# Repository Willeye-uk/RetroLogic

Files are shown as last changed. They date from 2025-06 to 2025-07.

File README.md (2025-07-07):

# **The RetroLogic 6502 SBC - KiCad 9 Files ([Ben Eater](https://eater.net/6502) Inspired)**

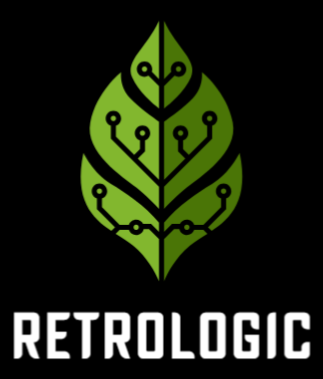
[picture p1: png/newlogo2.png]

---

Welcome to the repository for the **KiCad 9 design files** of a single board computer (SBC) based on the classic **W65C02S microprocessor**. This project draws heavy inspiration from [Ben Eater's excellent 6502 computer series](https://eater.net/6502), expanding upon it with a range of features for greater versatility and modern connectivity.

## **Features**

This SBC design aims to provide a robust platform for learning and experimenting with the 6502. Key features include:

* **W65C02S Processor:** Capable of running up to **14 MHz**.
* **Memory:**
    * **62256 SRAM:** For fast read/write memory operations.
    * **28C256 EEPROM:** For storing your programs and firmware.
* **Input/Output:**
    * **65C22 Versatile Interface Adapter (VIA):** Provides programmable parallel I/O, timers, and shift registers.
    * **65C51 Asynchronous Communications Interface Adapter (ACIA):** For serial communication capabilities.
* **Connectivity:**
    * **DB9 Serial Port:** Standard serial connector for PC communication (via MAX232 level shifter).
    * **FTDI Breakout Serial Socket:** Convenient header for connecting an FTDI serial-to-USB adapter.
    * **SD Card Socket:** For mass storage, enabling easier program loading and data logging.
    * **LCD Screen Connector:** Directly interface with character LCDs.
* **Power & Expansion:**
    * **USB-B Power Socket:** Modern and widely available power input.
    * **Power Switch:** For easy power control.
    * **Crystal Socket:** Flexible clocking options, allowing for different crystal frequencies.
    * **Switchable Voltage for Add-ons:** Provides configurable power for external modules and expansion boards.
    * **Expansion Port:** Example diagnostic board included.
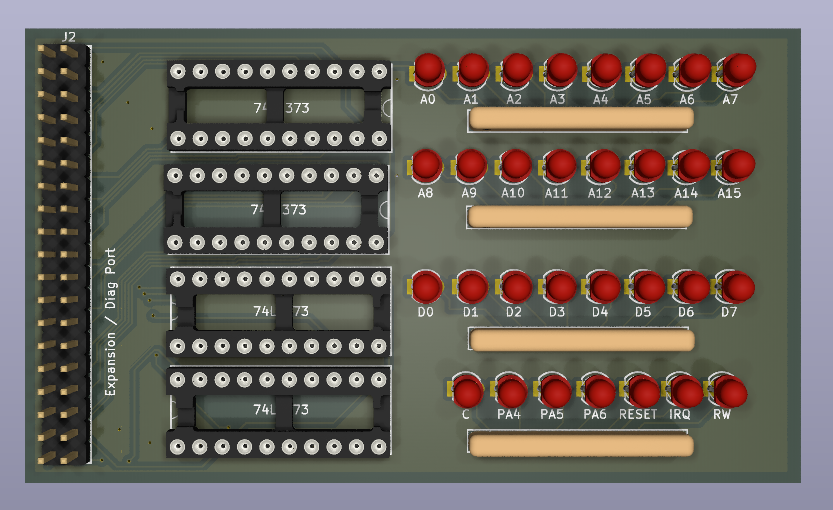
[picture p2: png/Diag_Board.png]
    
    * **Sound Card:** Expansion sound card and demo program.
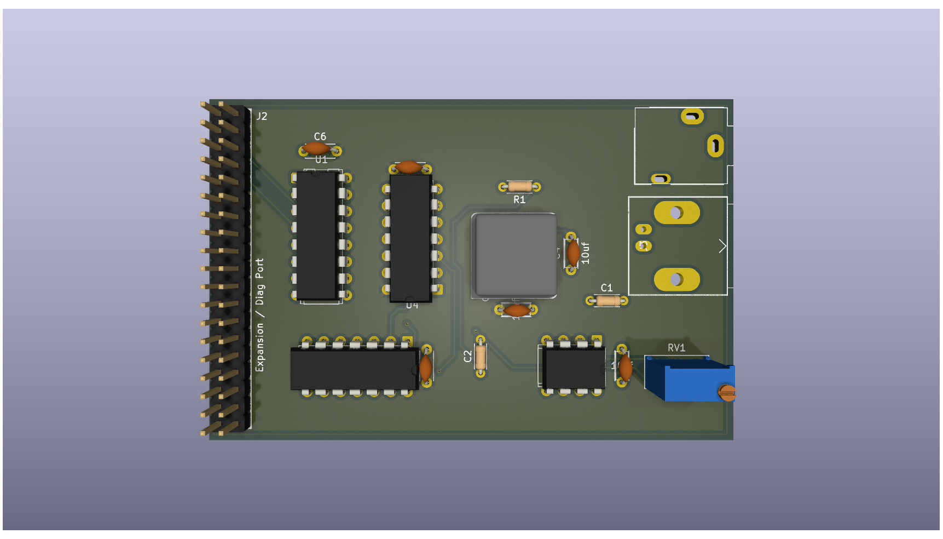
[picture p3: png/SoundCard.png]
    
    * **Terminal Card:** Expansion VGA terminal based on https://geoffg.net/terminal.html

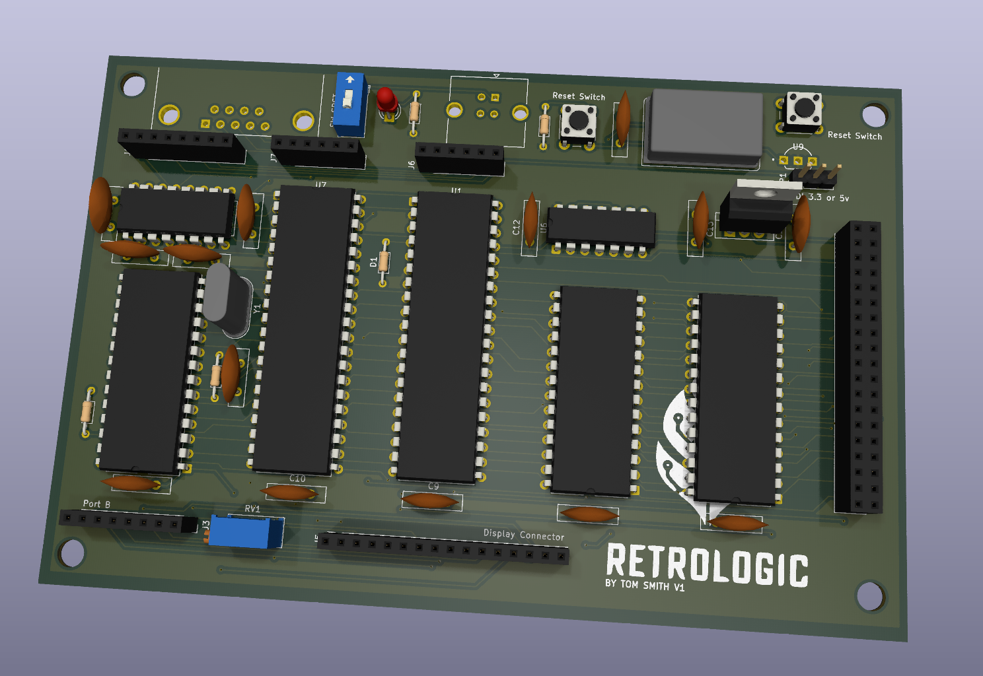
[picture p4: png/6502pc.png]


## **Getting Started**

To explore or modify this design, you'll need **KiCad 9**.

**Clone this repository: \
** Bash \
git clone https://github.com/Willeye-uk/RetroLogic.git

1. 
2. **Open the project in KiCad 9:** Navigate to the cloned directory and open the `.kicad_pro` file.

From there, you can view the schematics, examine the PCB layout, and generate manufacturing files if you wish to build your own board. Or use the ones provided in Gerber Files dir.

## **Contributing**

Contributions are welcome! If you find issues, have suggestions for improvements, or want to add features, feel free to open an issue or submit a pull request.

## **License**

This project is open-source. Please refer to the `LICENSE` file (if present) for details.

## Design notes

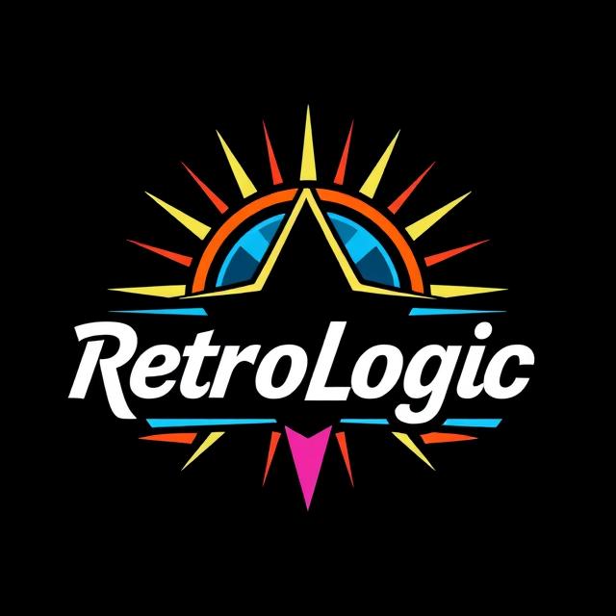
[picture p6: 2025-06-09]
png/output.jpg

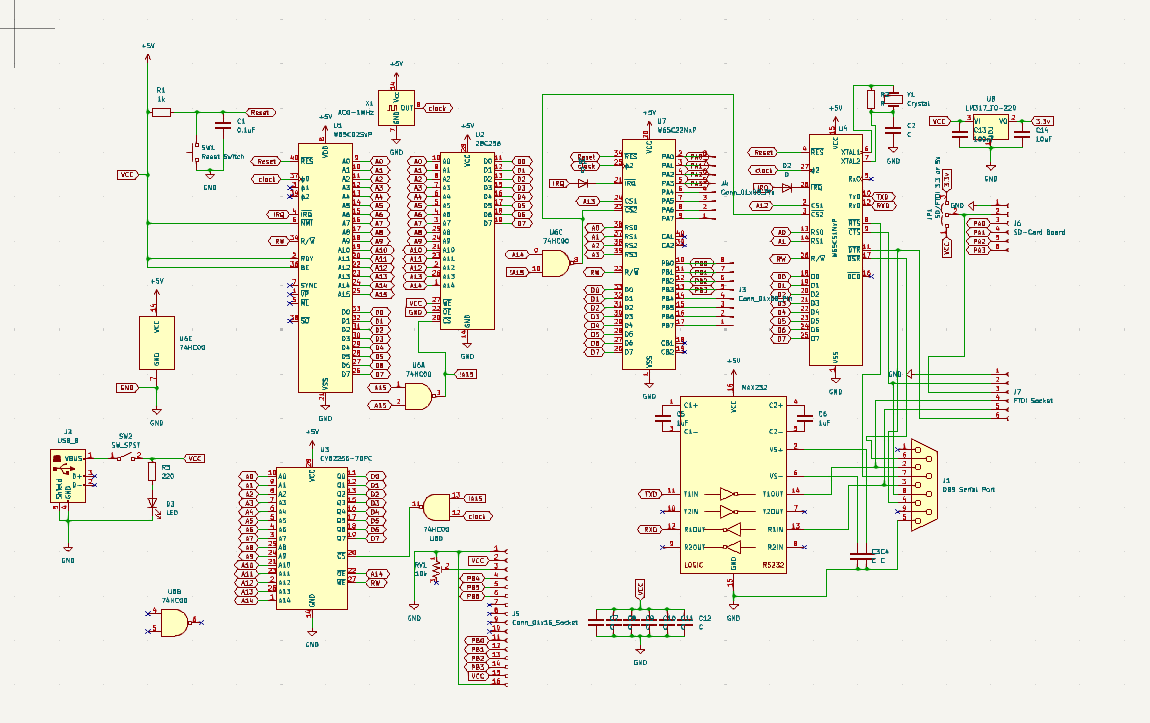
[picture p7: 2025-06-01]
png/layout1.png

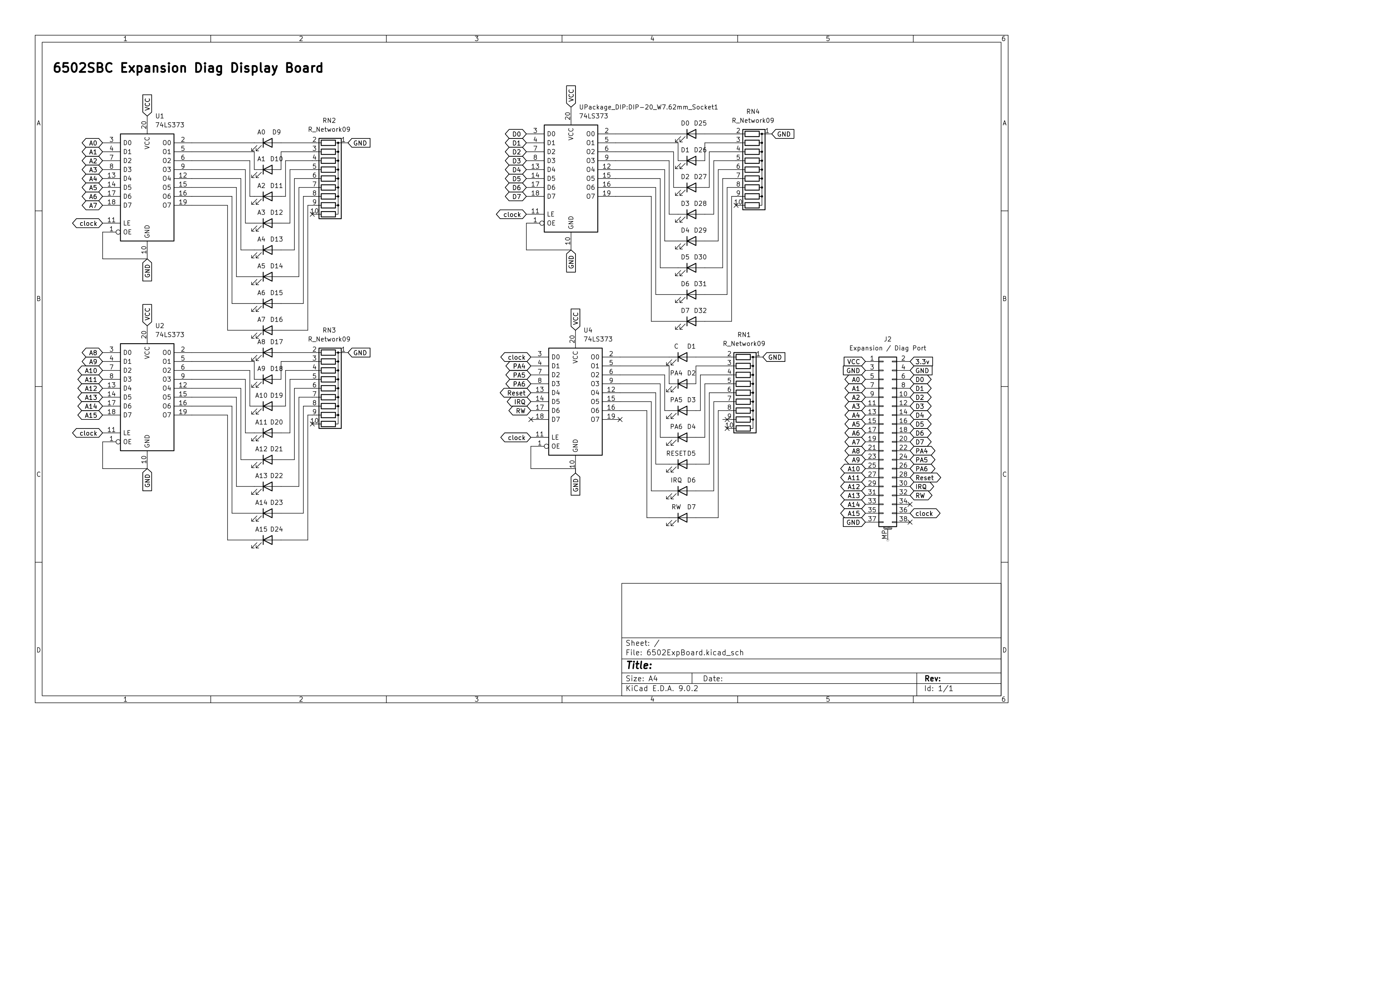
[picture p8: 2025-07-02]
png/Diag.png

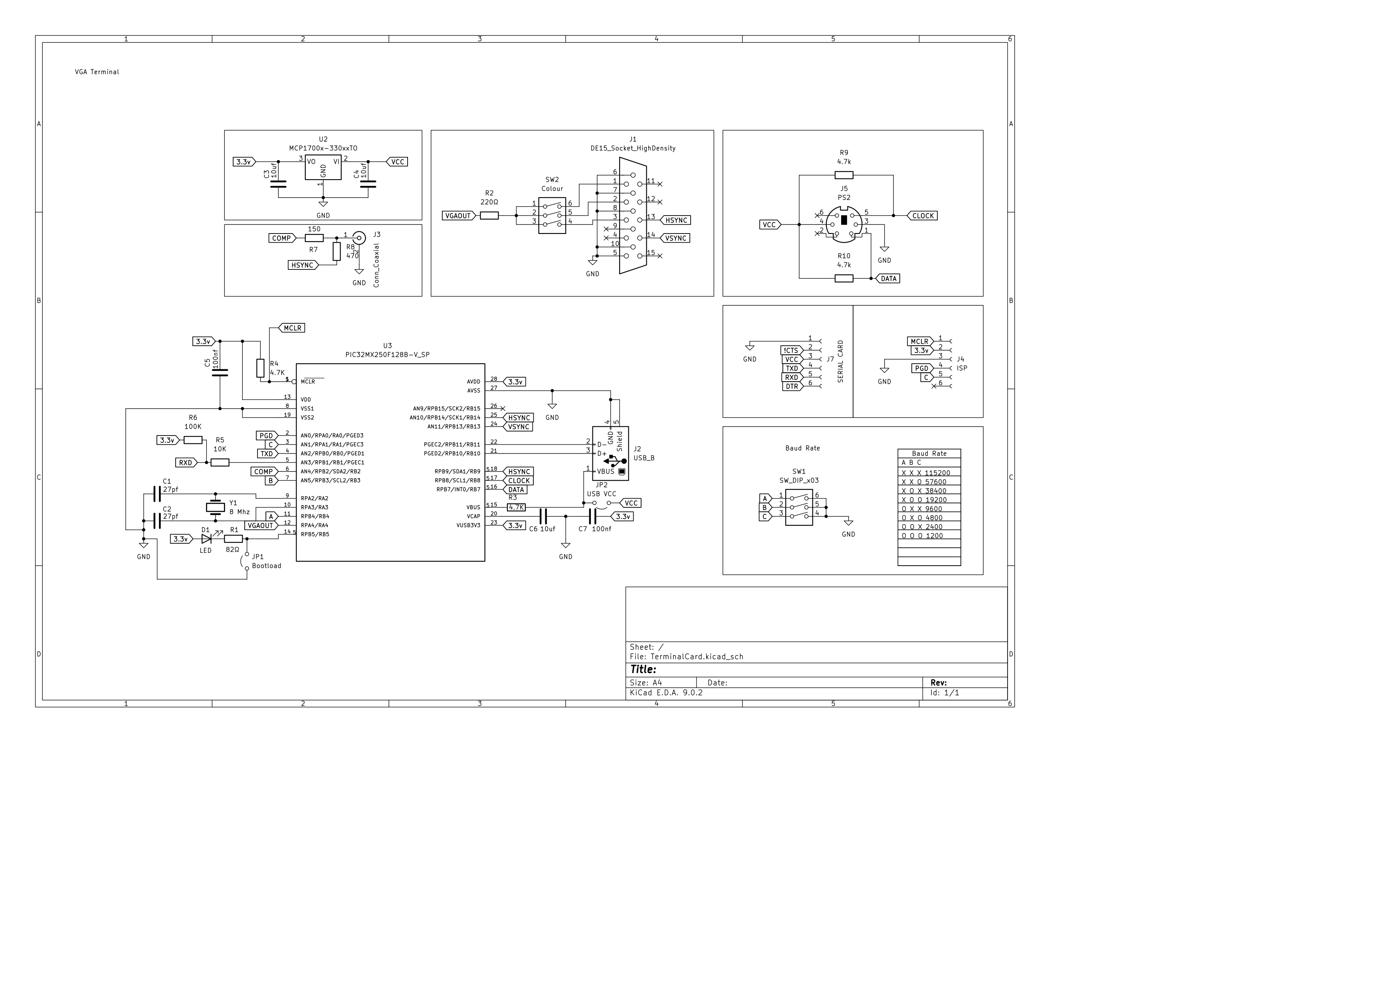
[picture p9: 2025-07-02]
png/terminal.png

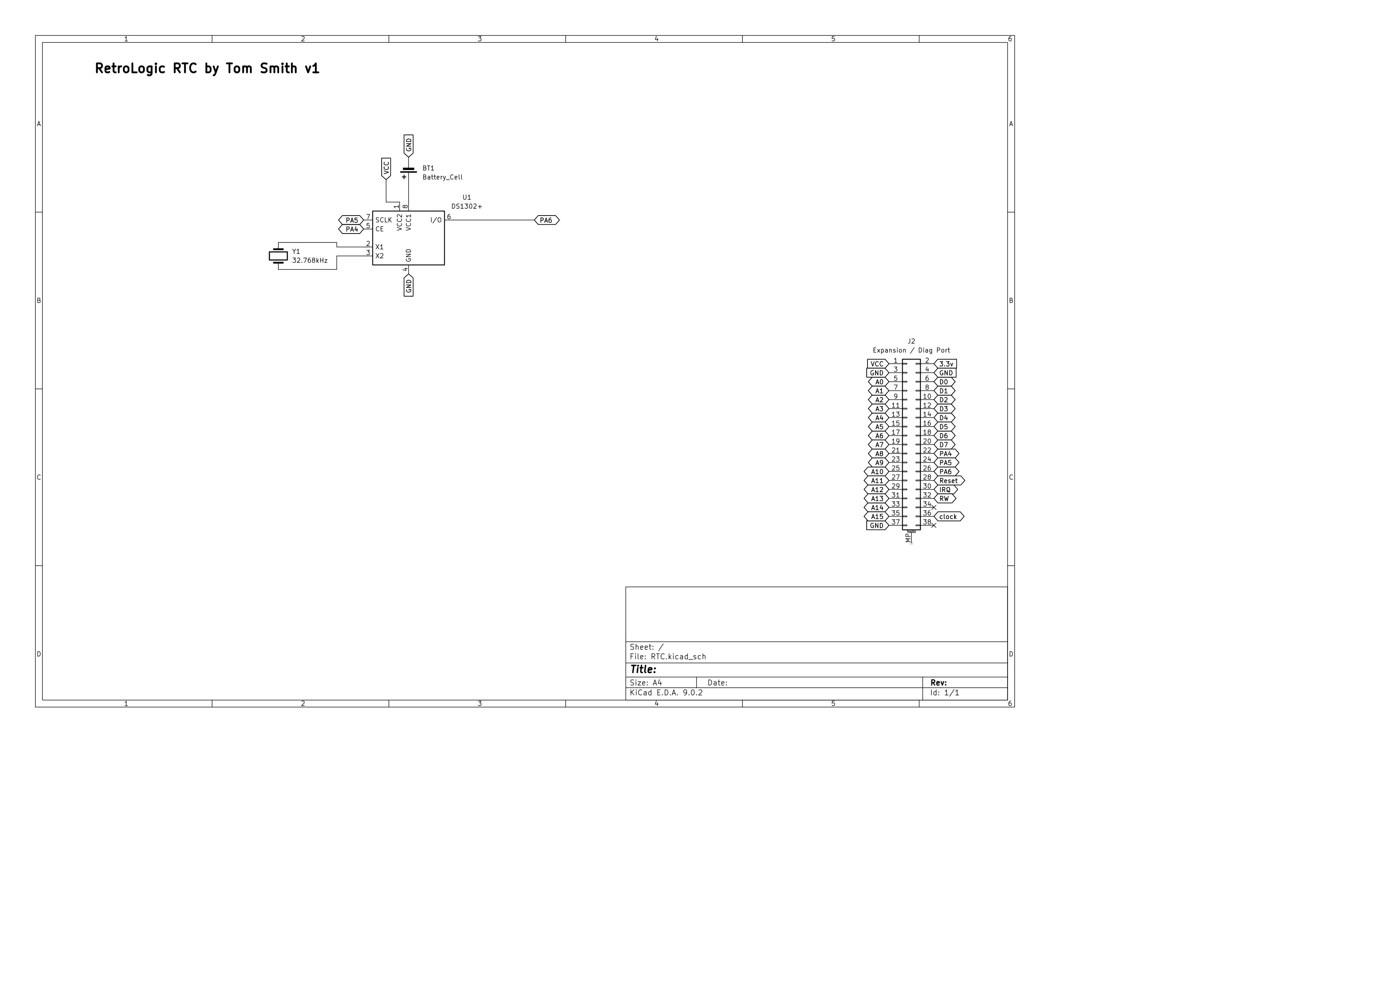
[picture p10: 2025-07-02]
png/rtc.png

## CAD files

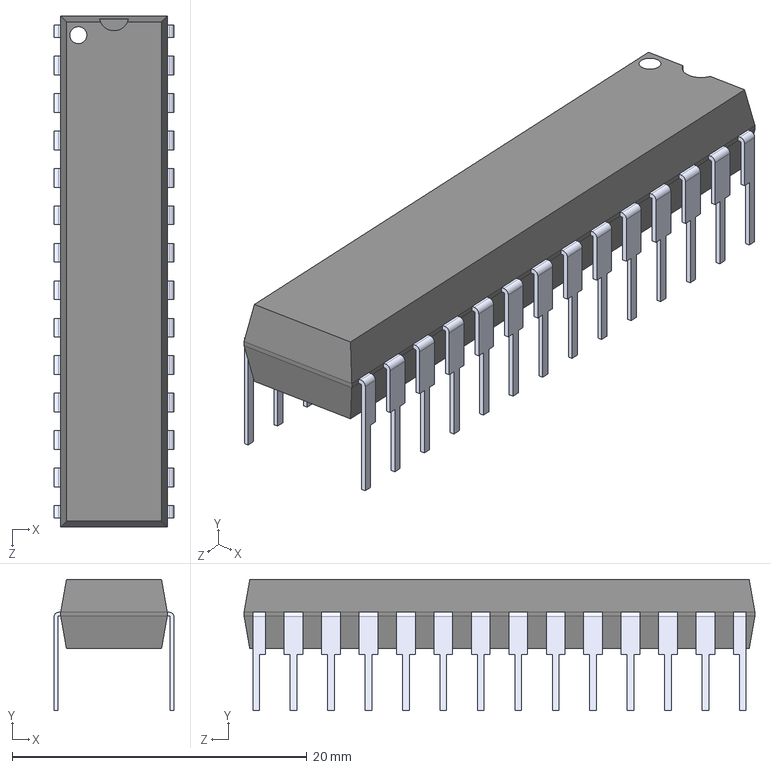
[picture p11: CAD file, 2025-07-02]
PIC32MX250F128B-V_SP/PIC32MX250F128B-V_SP.step
8.13 x 8.89 x 34.7 mm

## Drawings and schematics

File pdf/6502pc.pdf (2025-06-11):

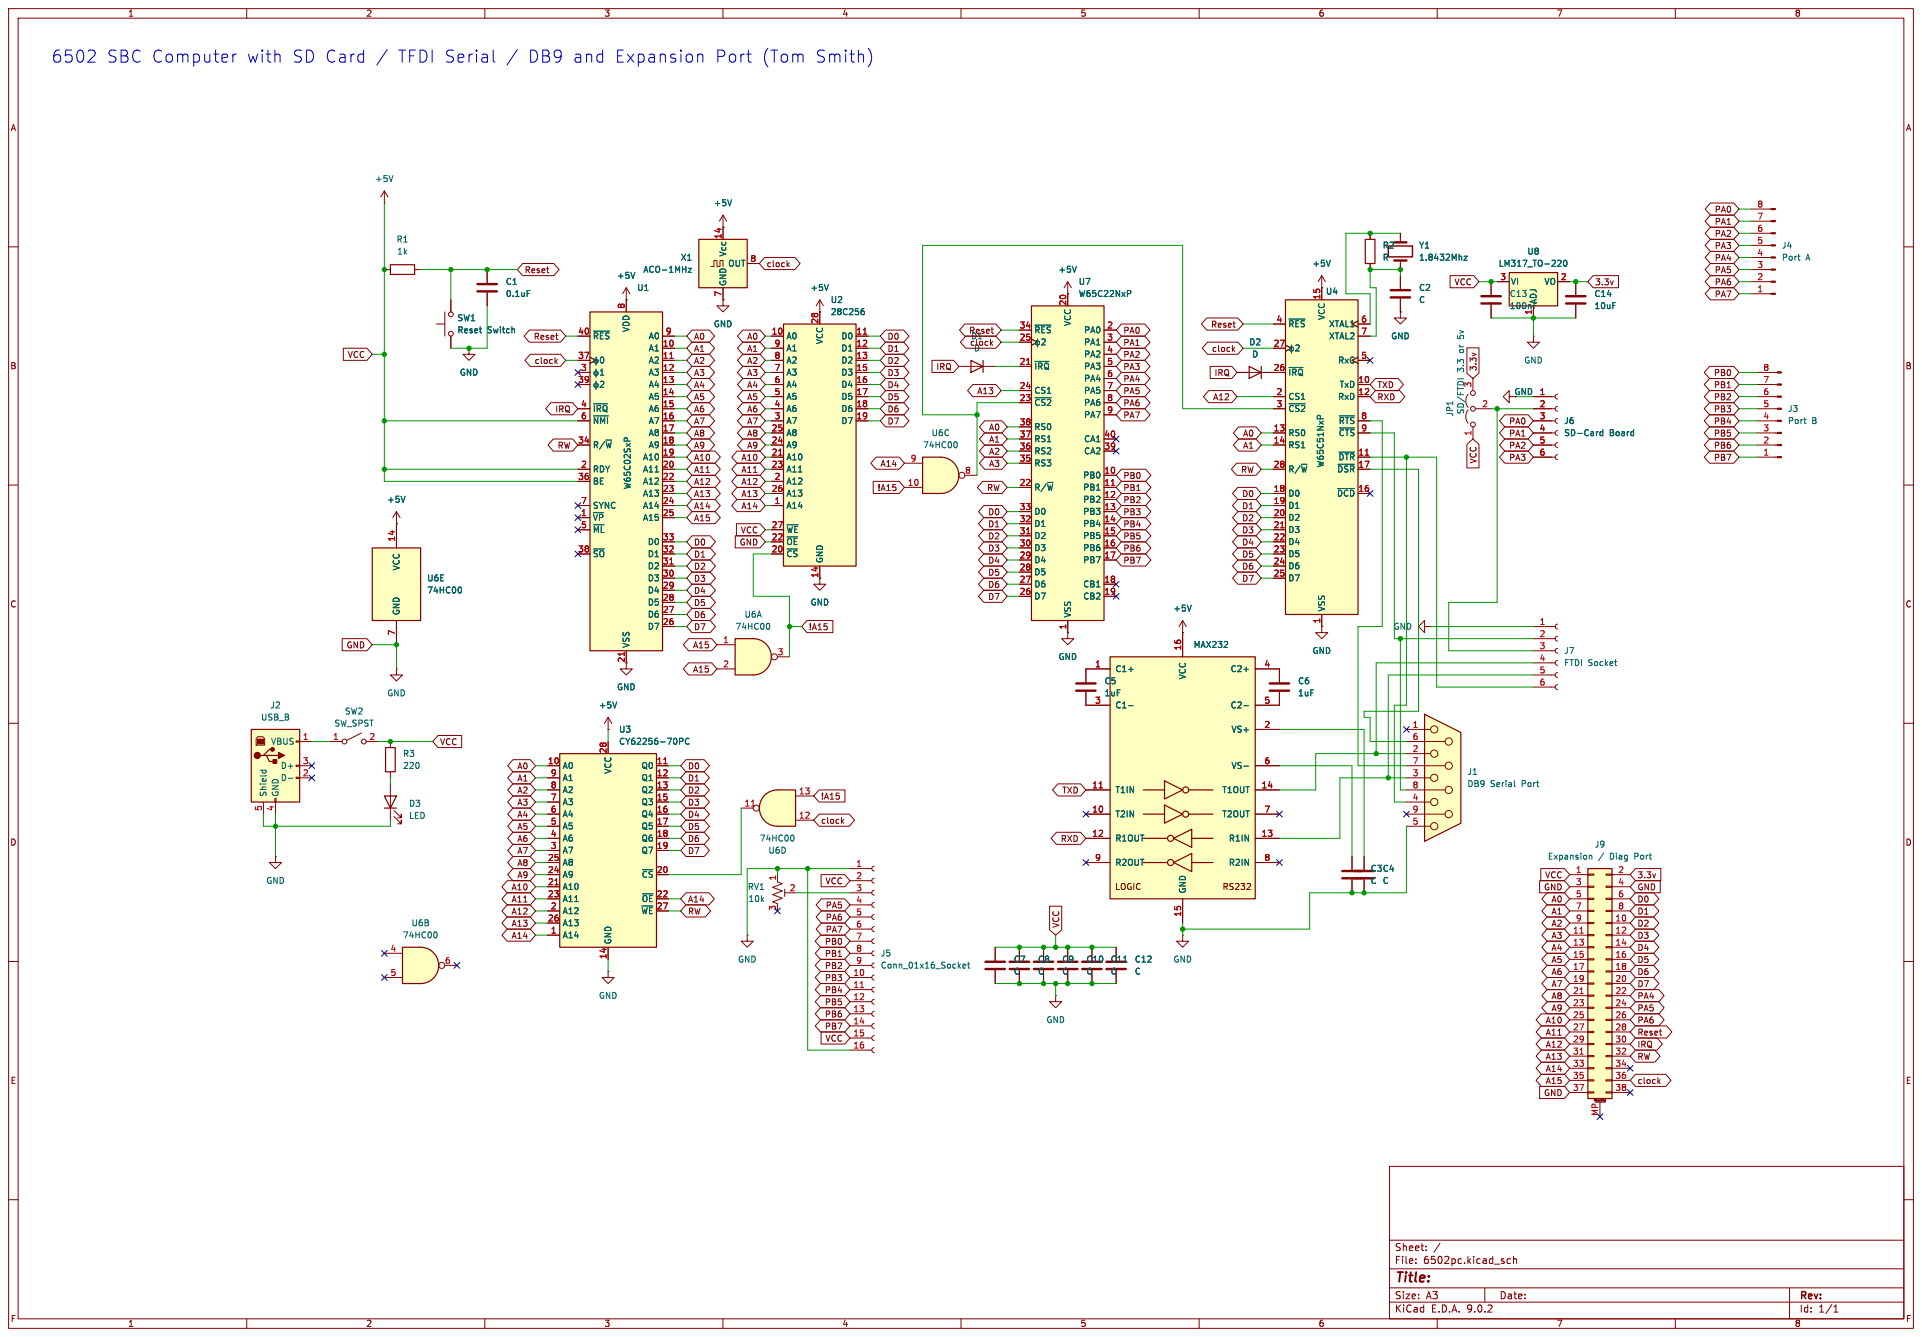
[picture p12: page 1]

6502 SBC Computer with SD Card / TFDI Serial / DB9 and Expansion Port (Tom Smith) C1

SW1 Reset Switch VCC 14 GND

1 XTAL1 6 XTAL2 7 RxC 5 TxD 10 RxD 12 ~{RTS}8 ~{CTS}9 ~{DTR} 11 ~{DSR} 17 ~{DCD} 16 R2 R
U4 W65C51NxP

1 XTAL1 6 XTAL2 7 RxC 5 TxD 10 RxD 12 ~{RTS}8 ~{CTS}9 ~{DTR} 11 ~{DSR} 17 ~{DCD} 16 U4 W65C51NxP

3 JP1 SD/FTDI 3.3 or 5v C10 C GND

Id: 1/1 Title: File: 6502pc.kicad_sch Sheet: /

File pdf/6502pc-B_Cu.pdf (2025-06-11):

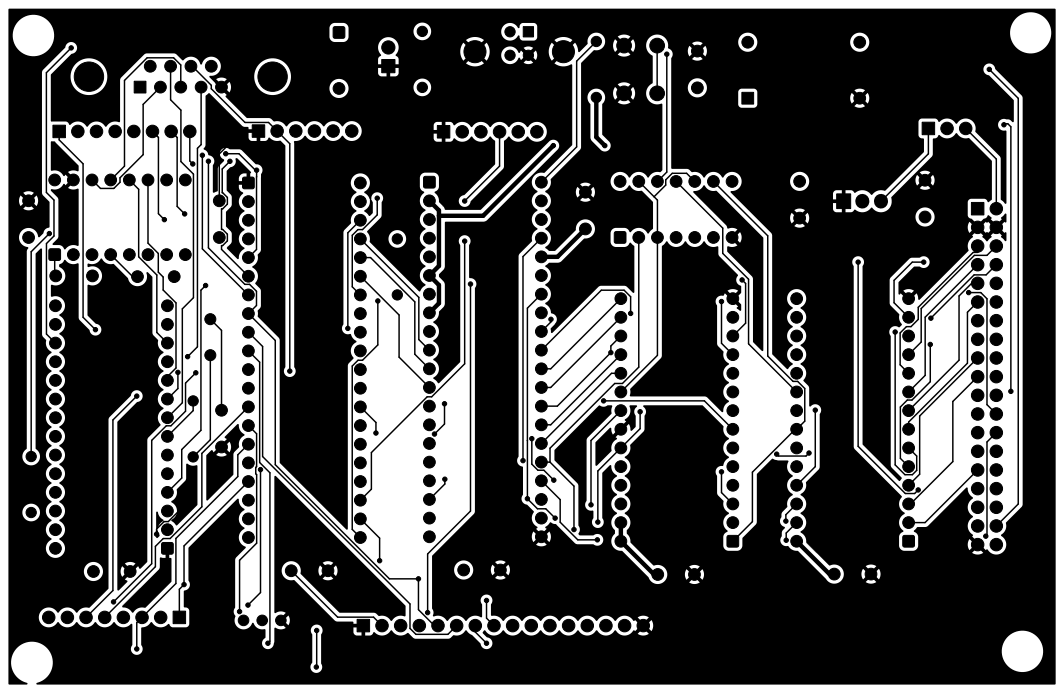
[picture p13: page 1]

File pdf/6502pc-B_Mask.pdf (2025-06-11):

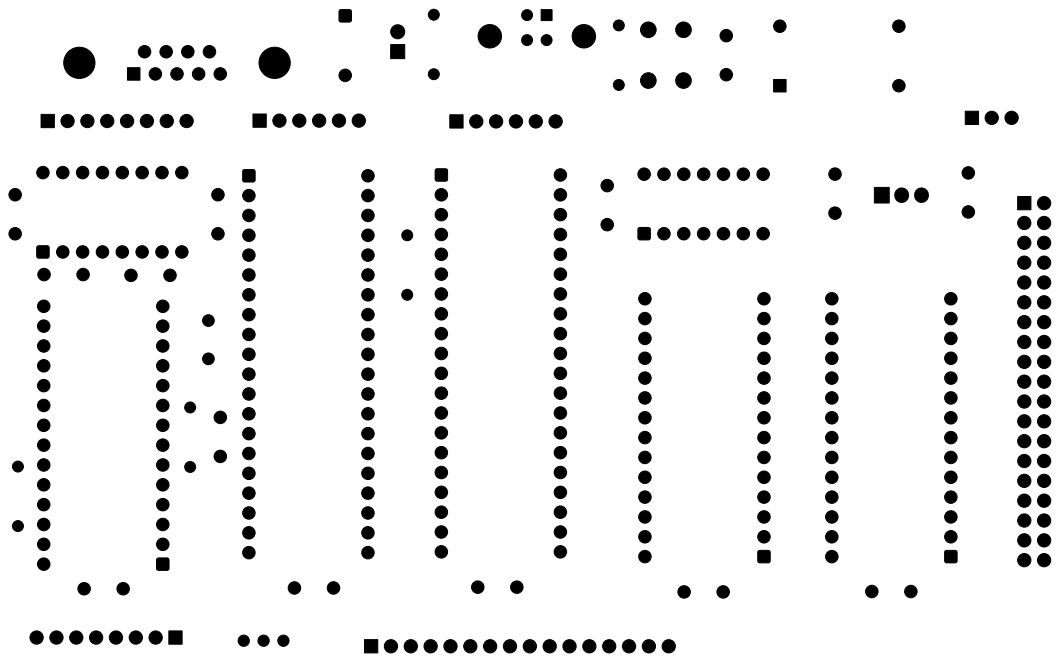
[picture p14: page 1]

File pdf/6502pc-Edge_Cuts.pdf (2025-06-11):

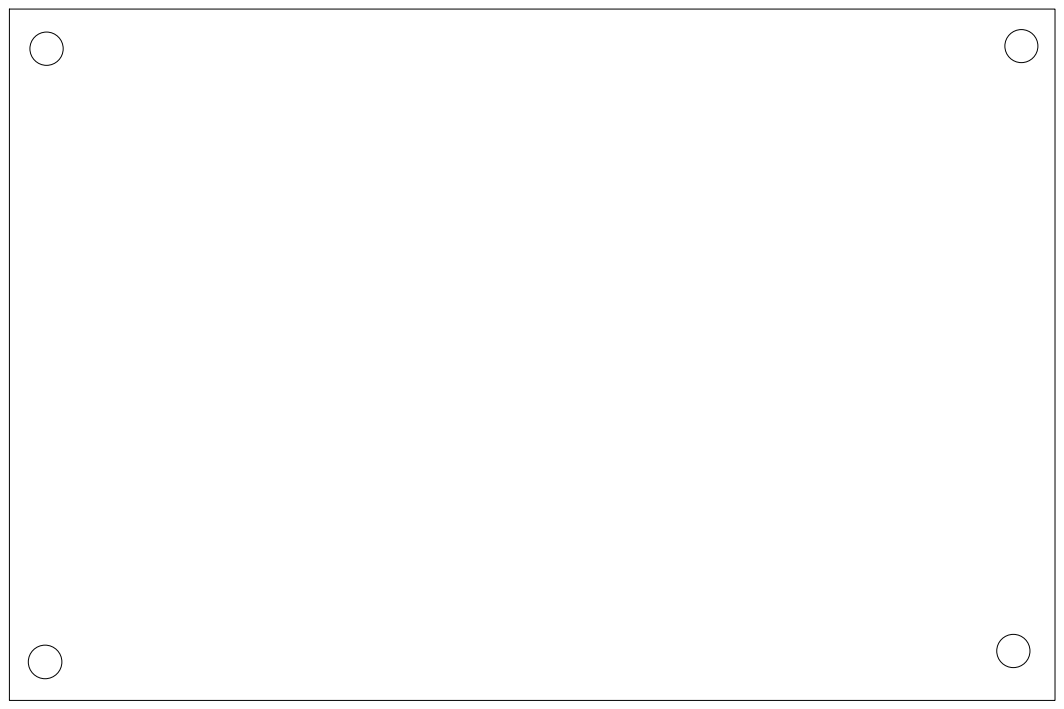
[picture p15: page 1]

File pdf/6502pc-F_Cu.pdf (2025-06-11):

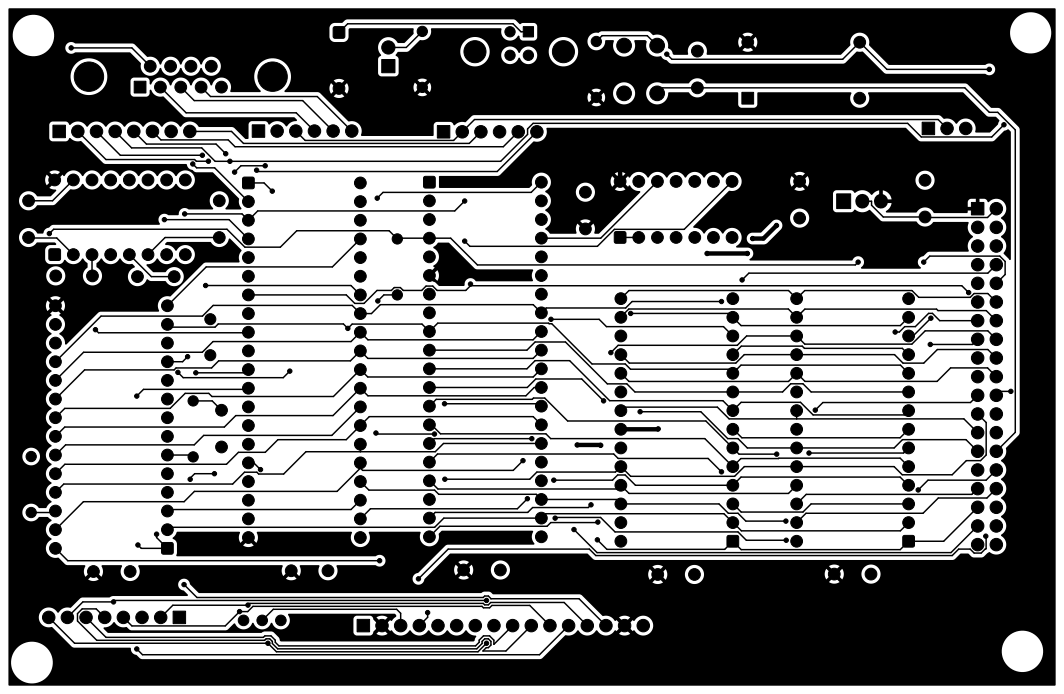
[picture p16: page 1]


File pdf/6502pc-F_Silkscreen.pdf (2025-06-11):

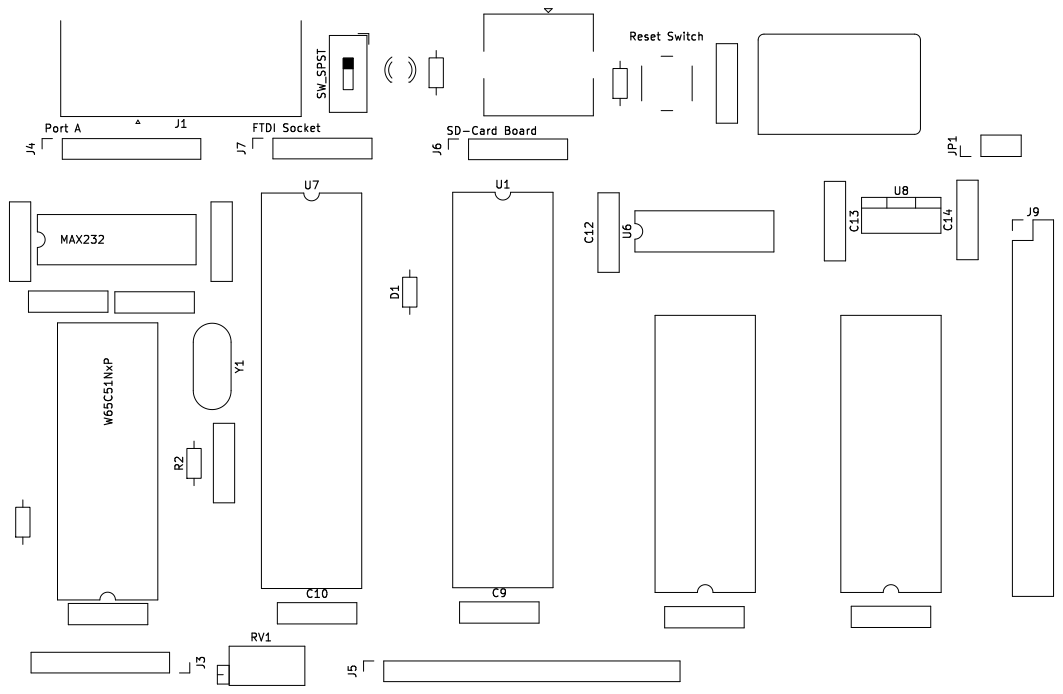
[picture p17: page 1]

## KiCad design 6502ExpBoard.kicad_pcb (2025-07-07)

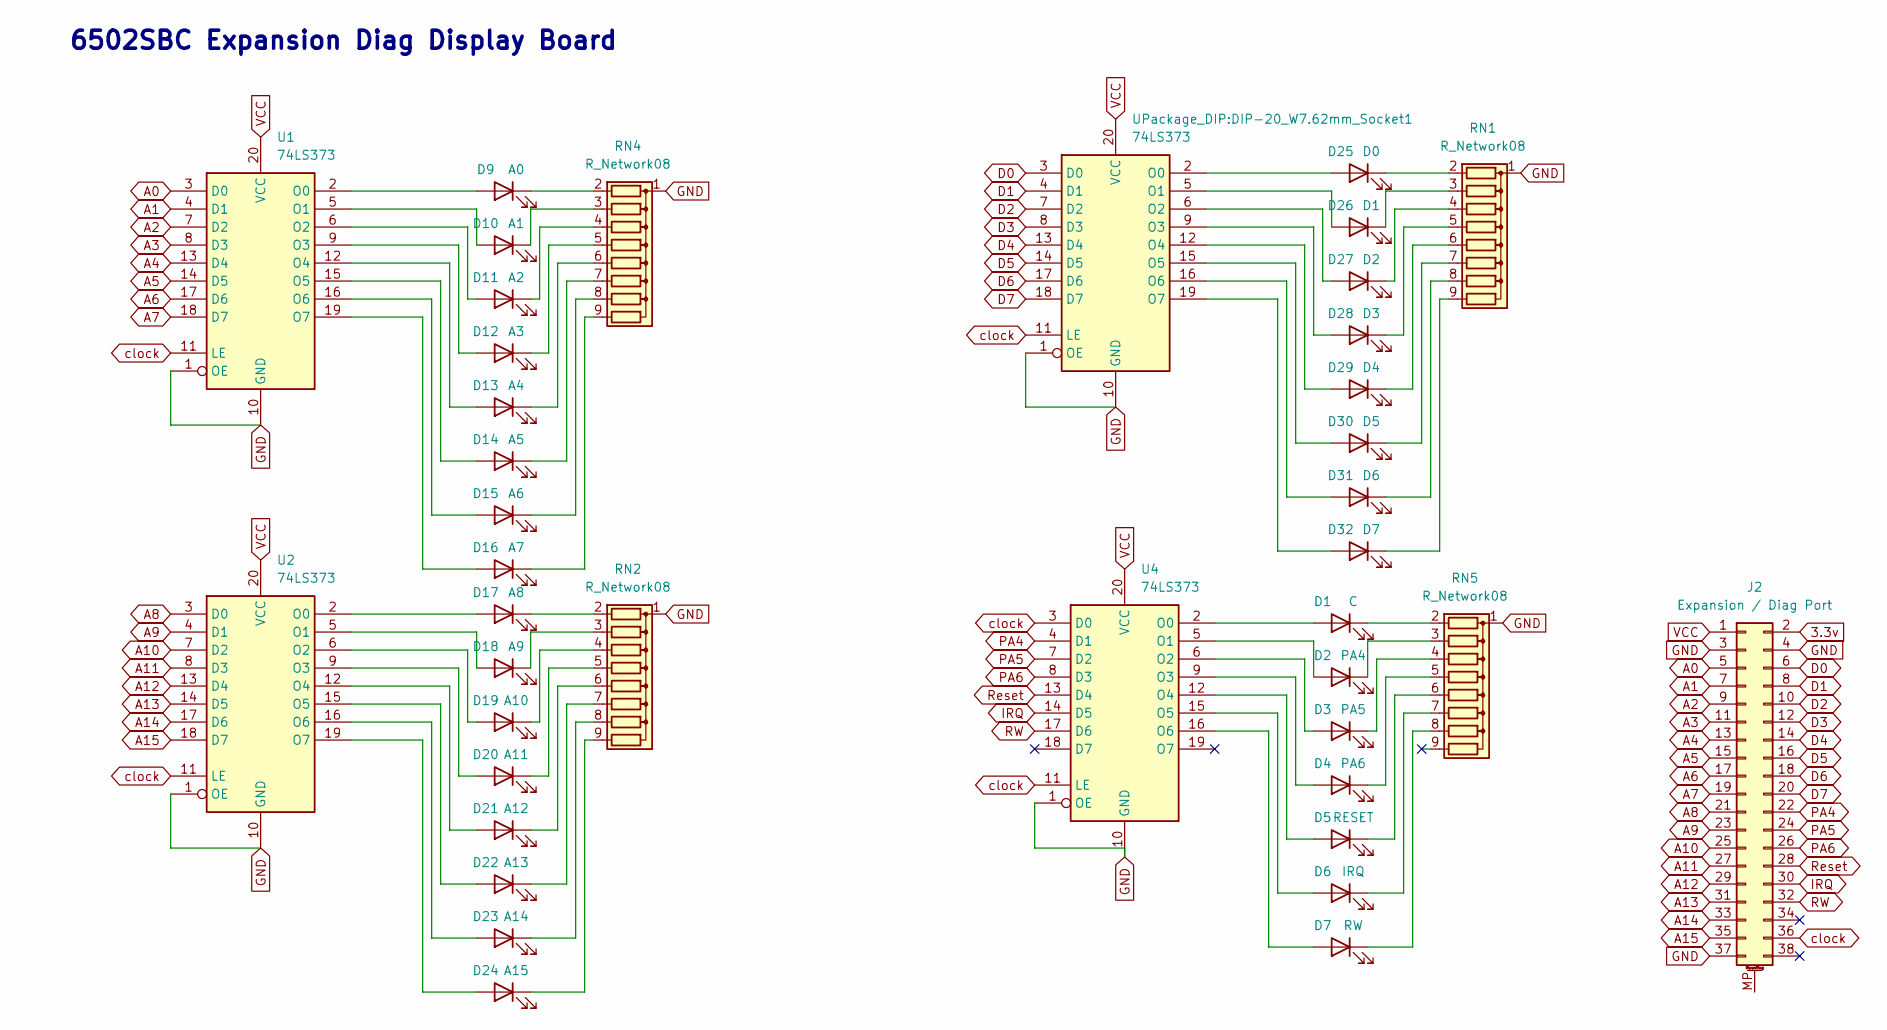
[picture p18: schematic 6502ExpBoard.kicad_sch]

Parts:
D1: C; LED_D3.0mm
D2: PA4; LED_D3.0mm
D3: PA5; LED_D3.0mm
D4: PA6; LED_D3.0mm
D5: RESET; LED_D3.0mm
D6: IRQ; LED_D3.0mm
D7: RW; LED_D3.0mm
D9: A0; LED_D3.0mm
D10: A1; LED_D3.0mm
D11: A2; LED_D3.0mm
D12: A3; LED_D3.0mm
D13: A4; LED_D3.0mm
D14: A5; LED_D3.0mm
D15: A6; LED_D3.0mm
D16: A7; LED_D3.0mm
D17: A8; LED_D3.0mm
D18: A9; LED_D3.0mm
D19: A10; LED_D3.0mm
D20: A11; LED_D3.0mm
D21: A12; LED_D3.0mm
D22: A13; LED_D3.0mm
D23: A14; LED_D3.0mm
D24: A15; LED_D3.0mm
D25: D0; LED_D3.0mm
D26: D1; LED_D3.0mm
D27: D2; LED_D3.0mm
D28: D3; LED_D3.0mm
D29: D4; LED_D3.0mm
D30: D5; LED_D3.0mm
D31: D6; LED_D3.0mm
D32: D7; LED_D3.0mm
J2: Expansion / Diag Port; PinHeader_2x19_P2.54mm_Vertical
RN1, RN2, RN4, RN5: R_Network08; R_Array_SIP9
U1, U2, U4: 74LS373; DIP-20_W7.62mm_Socket
UPackage_DIP:DIP-20_W7.62mm_Socket1: 74LS373; DIP-20_W7.62mm_Socket

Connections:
3.3v: J2.2
A0: J2.5, U1.3 (D0)
A1: J2.7, U1.4 (D1)
A2: J2.9, U1.7 (D2)
A3: J2.11, U1.8 (D3)
A4: J2.13, U1.13 (D4)
A5: J2.15, U1.14 (D5)
A6: J2.17, U1.17 (D6)
A7: J2.19, U1.18 (D7)
A8: J2.21, U2.3 (D0)
A9: J2.23, U2.4 (D1)
A10: J2.25, U2.7 (D2)
A11: J2.27, U2.8 (D3)
A12: J2.29, U2.13 (D4)
A13: J2.31, U2.14 (D5)
A14: J2.33, U2.17 (D6)
A15: J2.35, U2.18 (D7)
D0: J2.6, UPackage_DIP:DIP-20_W7.62mm_Socket1.3 (D0)
D1: J2.8, UPackage_DIP:DIP-20_W7.62mm_Socket1.4 (D1)
D2: J2.10, UPackage_DIP:DIP-20_W7.62mm_Socket1.7 (D2)
D3: J2.12, UPackage_DIP:DIP-20_W7.62mm_Socket1.8 (D3)
D4: J2.14, UPackage_DIP:DIP-20_W7.62mm_Socket1.13 (D4)
D5: J2.16, UPackage_DIP:DIP-20_W7.62mm_Socket1.14 (D5)
D6: J2.18, UPackage_DIP:DIP-20_W7.62mm_Socket1.17 (D6)
D7: J2.20, UPackage_DIP:DIP-20_W7.62mm_Socket1.18 (D7)
GND: J2.3, J2.4, J2.37, RN1.1 (common), RN2.1 (common), RN4.1 (common), RN5.1 (common), U1.1 (OE), U1.10 (GND), U2.1 (OE), U2.10 (GND), U4.1 (OE), U4.10 (GND), UPackage_DIP:DIP-20_W7.62mm_Socket1.1 (OE), UPackage_DIP:DIP-20_W7.62mm_Socket1.10 (GND)
IRQ: J2.30, U4.14 (D5)
unnamed: D1.2 (A), U4.2 (O0)
unnamed: D1.1 (K), RN5.2 (R1)
unnamed: D2.2 (A), U4.5 (O1)
unnamed: D2.1 (K), RN5.3 (R2)
unnamed: D3.2 (A), U4.6 (O2)
unnamed: D3.1 (K), RN5.4 (R3)
unnamed: D4.2 (A), U4.9 (O3)
unnamed: D4.1 (K), RN5.5 (R4)
unnamed: D5.2 (A), U4.12 (O4)
unnamed: D5.1 (K), RN5.6 (R5)
unnamed: D6.2 (A), U4.15 (O5)
unnamed: D6.1 (K), RN5.7 (R6)
unnamed: D7.2 (A), U4.16 (O6)
unnamed: D7.1 (K), RN5.8 (R7)
unnamed: D9.2 (A), U1.2 (O0)
unnamed: D9.1 (K), RN4.2 (R1)
unnamed: D10.2 (A), U1.5 (O1)
unnamed: D10.1 (K), RN4.3 (R2)
unnamed: D11.2 (A), U1.6 (O2)
unnamed: D11.1 (K), RN4.4 (R3)
unnamed: D12.2 (A), U1.9 (O3)
unnamed: D12.1 (K), RN4.5 (R4)
unnamed: D13.2 (A), U1.12 (O4)
unnamed: D13.1 (K), RN4.6 (R5)
unnamed: D14.2 (A), U1.15 (O5)
unnamed: D14.1 (K), RN4.7 (R6)
unnamed: D15.2 (A), U1.16 (O6)
unnamed: D15.1 (K), RN4.8 (R7)
unnamed: D16.2 (A), U1.19 (O7)
unnamed: D16.1 (K), RN4.9 (R8)
unnamed: D17.2 (A), U2.2 (O0)
unnamed: D17.1 (K), RN2.2 (R1)
unnamed: D18.2 (A), U2.5 (O1)
unnamed: D18.1 (K), RN2.3 (R2)
unnamed: D19.2 (A), U2.6 (O2)
unnamed: D19.1 (K), RN2.4 (R3)
unnamed: D20.2 (A), U2.9 (O3)
unnamed: D20.1 (K), RN2.5 (R4)
unnamed: D21.2 (A), U2.12 (O4)
unnamed: D21.1 (K), RN2.6 (R5)
unnamed: D22.2 (A), U2.15 (O5)
unnamed: D22.1 (K), RN2.7 (R6)
unnamed: D23.2 (A), U2.16 (O6)
unnamed: D23.1 (K), RN2.8 (R7)
unnamed: D24.2 (A), U2.19 (O7)
unnamed: D24.1 (K), RN2.9 (R8)
unnamed: D25.2 (A), UPackage_DIP:DIP-20_W7.62mm_Socket1.2 (O0)
unnamed: D25.1 (K), RN1.2 (R1)
unnamed: D26.2 (A), UPackage_DIP:DIP-20_W7.62mm_Socket1.5 (O1)
unnamed: D26.1 (K), RN1.3 (R2)
unnamed: D27.2 (A), UPackage_DIP:DIP-20_W7.62mm_Socket1.6 (O2)
unnamed: D27.1 (K), RN1.4 (R3)
unnamed: D28.2 (A), UPackage_DIP:DIP-20_W7.62mm_Socket1.9 (O3)
unnamed: D28.1 (K), RN1.5 (R4)
unnamed: D29.2 (A), UPackage_DIP:DIP-20_W7.62mm_Socket1.12 (O4)
unnamed: D29.1 (K), RN1.6 (R5)
unnamed: D30.2 (A), UPackage_DIP:DIP-20_W7.62mm_Socket1.15 (O5)
unnamed: D30.1 (K), RN1.7 (R6)
unnamed: D31.2 (A), UPackage_DIP:DIP-20_W7.62mm_Socket1.16 (O6)
unnamed: D31.1 (K), RN1.8 (R7)
unnamed: D32.2 (A), UPackage_DIP:DIP-20_W7.62mm_Socket1.19 (O7)
unnamed: D32.1 (K), RN1.9 (R8)
PA4: J2.22, U4.4 (D1)
PA5: J2.24, U4.7 (D2)
PA6: J2.26, U4.8 (D3)
RW: J2.32, U4.17 (D6)
Reset: J2.28, U4.13 (D4)
VCC: J2.1, U1.20 (VCC), U2.20 (VCC), U4.20 (VCC), UPackage_DIP:DIP-20_W7.62mm_Socket1.20 (VCC)
clock: J2.36, U1.11 (LE), U2.11 (LE), U4.3 (D0), U4.11 (LE), UPackage_DIP:DIP-20_W7.62mm_Socket1.11 (LE)

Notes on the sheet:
6502SBC Expansion Diag Display Board

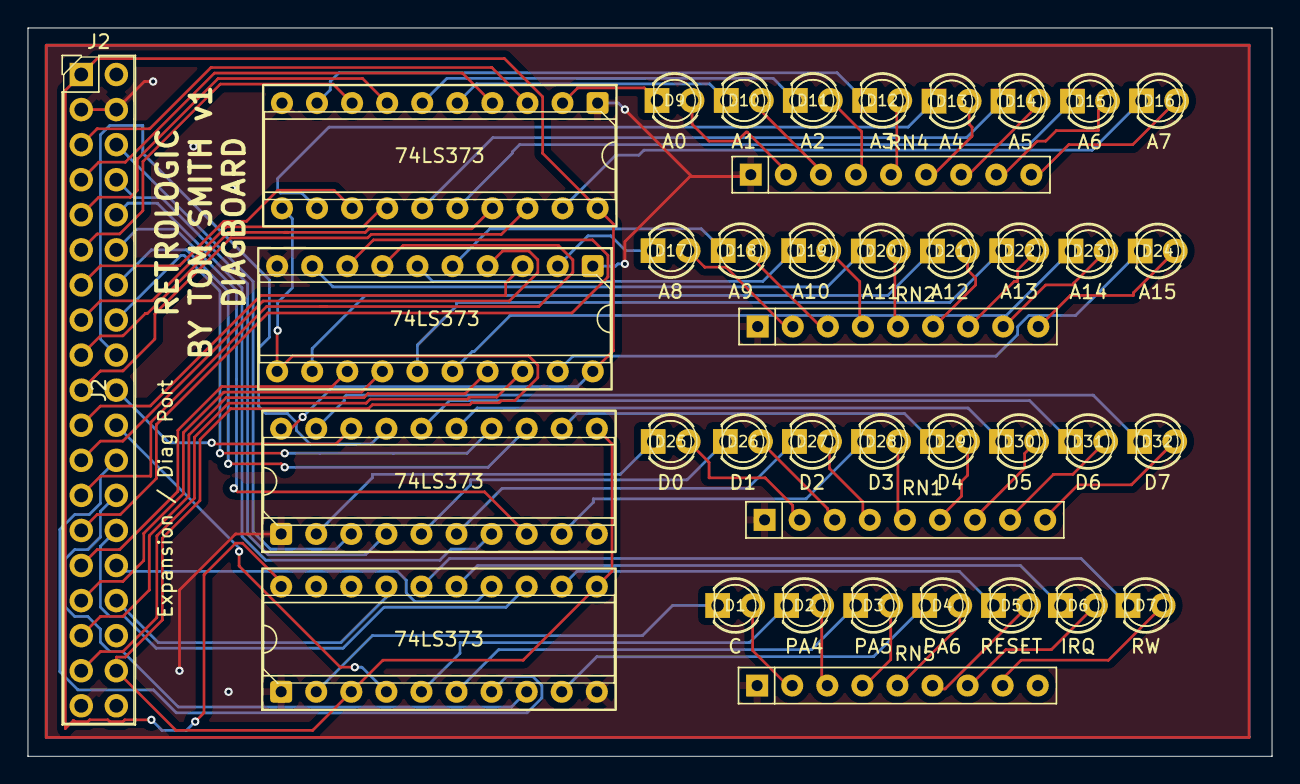
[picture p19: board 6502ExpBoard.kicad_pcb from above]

Board: 2 copper layers, 90.1 x 52.8 mm, 40 parts (0 on the bottom side), 95 nets.

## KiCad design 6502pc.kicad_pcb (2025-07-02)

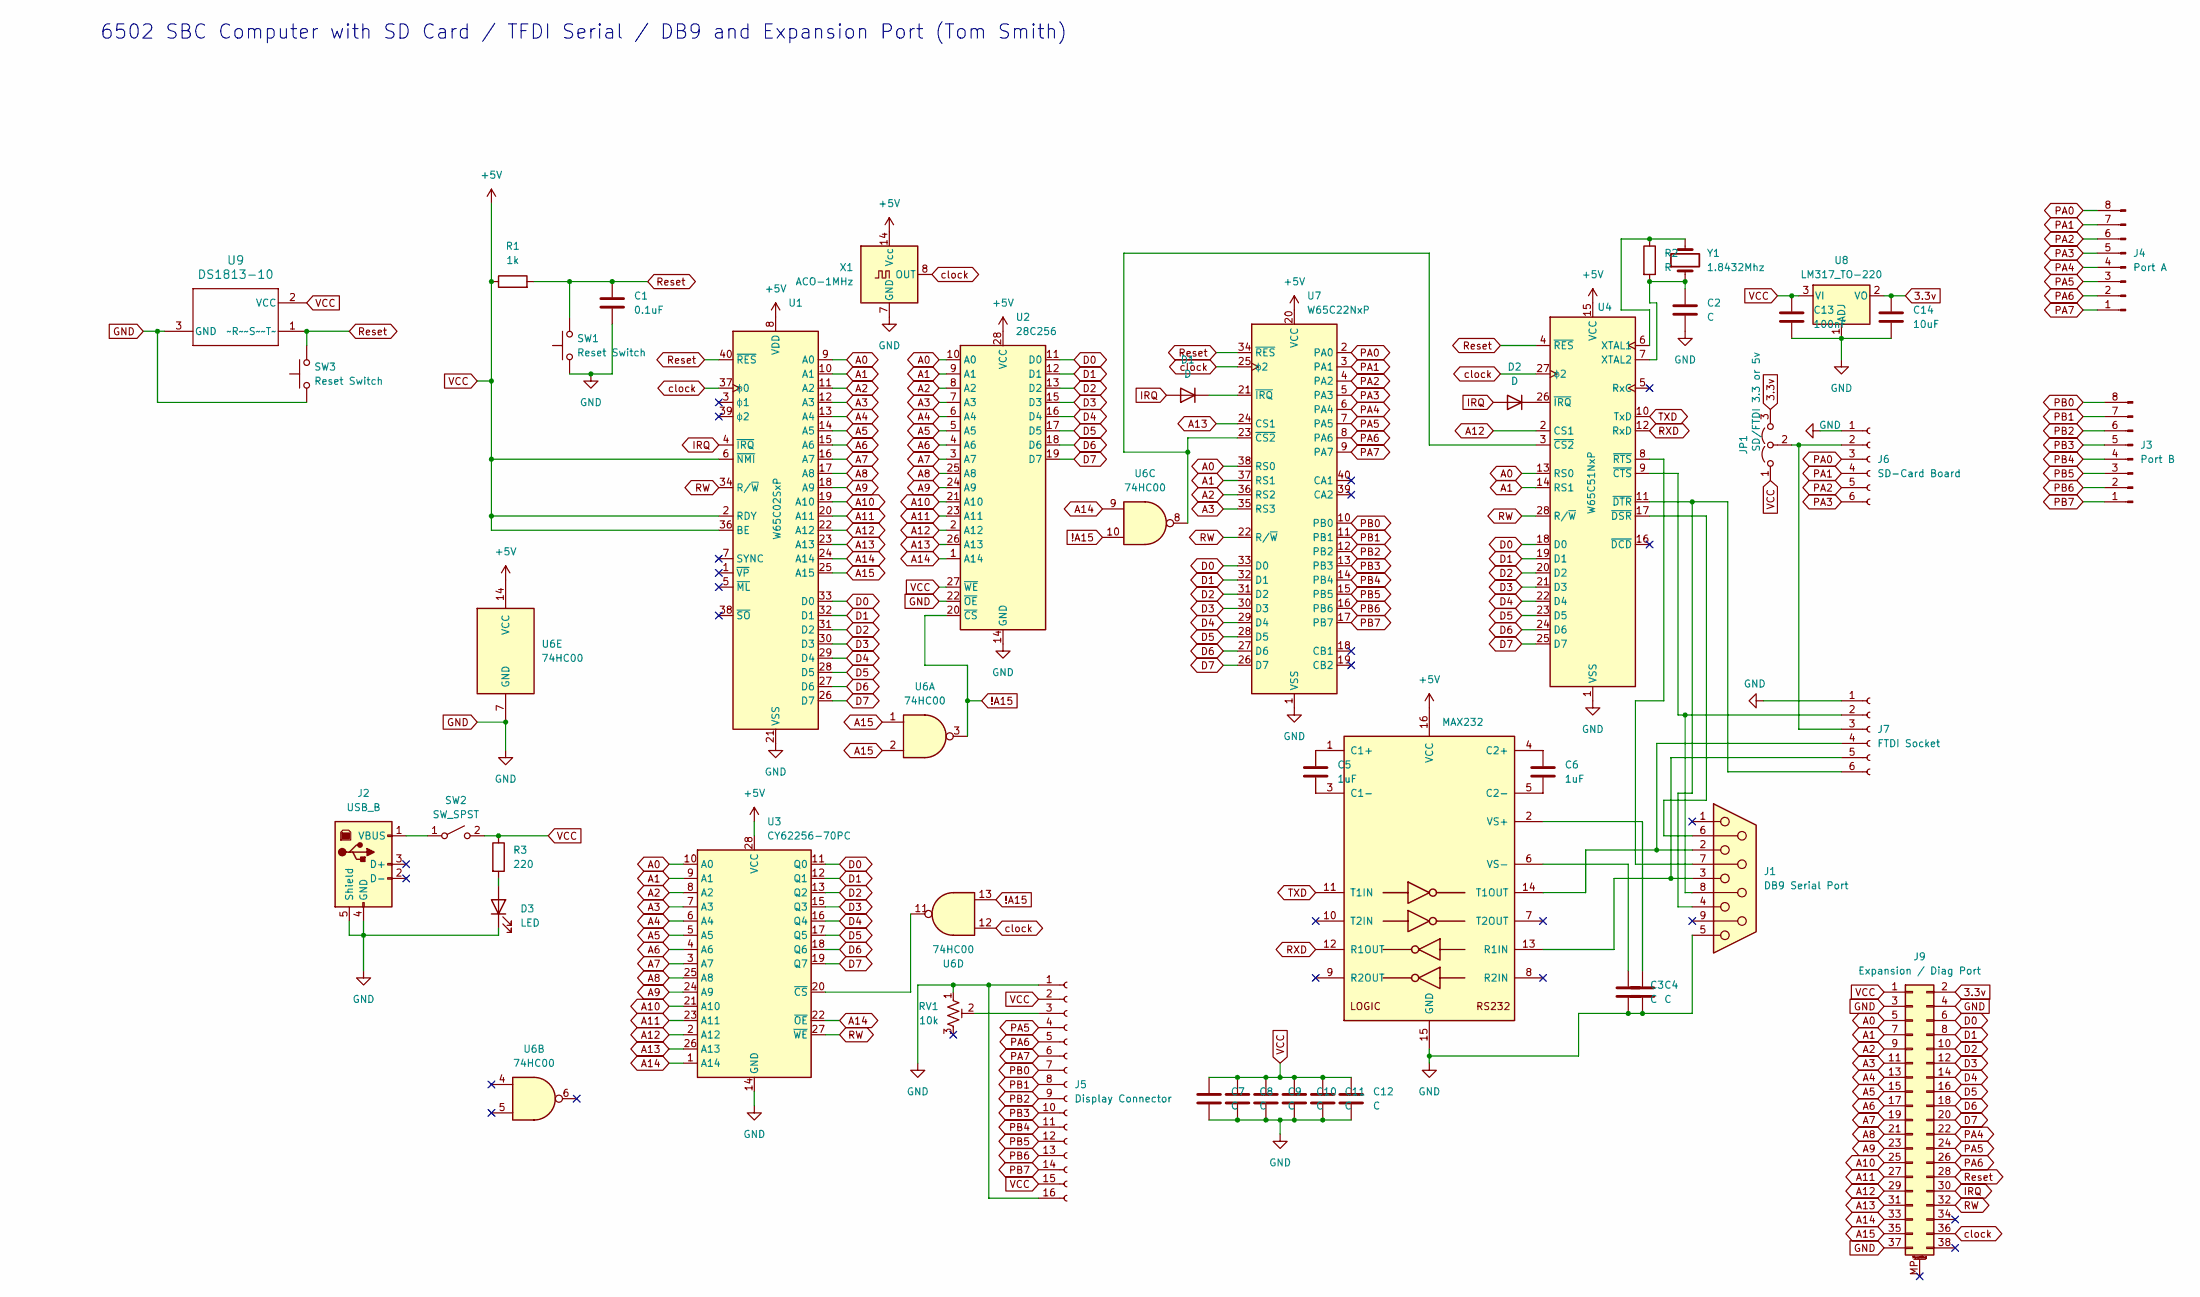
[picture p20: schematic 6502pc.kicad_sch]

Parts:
C1: 0.1uF; C_Disc_D10.0mm_W2.5mm_P5.00mm
C2, C3, C4, C7, C8, C9, C10, C11, C12: C; C_Disc_D10.0mm_W2.5mm_P5.00mm
C5, C6: 1uF; C_Disc_D10.0mm_W2.5mm_P5.00mm
C13: 100nF; C_Disc_D10.0mm_W2.5mm_P5.00mm
C14: 10uF; C_Disc_D10.0mm_W2.5mm_P5.00mm
D1, D2: D; R_Axial_DIN0204_L3.6mm_D1.6mm_P7.62mm_Horizontal
D3: LED; LED_D3.0mm
J1: DB9 Serial Port; DSUB-9_Female_Horizontal_P2.77x2.84mm_EdgePinOffset7.70mm_H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
J2: USB_B; USB_B_TE_5787834_Vertical
J3: Port B; PinSocket_1x08_P2.54mm_Vertical
J4: Port A; PinSocket_1x08_P2.54mm_Vertical
J5: Display Connector; PinSocket_1x16_P2.54mm_Vertical
J6: SD-Card Board; PinSocket_1x06_P2.54mm_Vertical
J7: FTDI Socket; PinSocket_1x06_P2.54mm_Vertical
J9: Expansion / Diag Port; PinSocket_2x19_P2.54mm_Vertical
JP1: SD/FTDI 3.3 or 5v; PinHeader_1x03_P2.54mm_Vertical
R1: 1k; R_Axial_DIN0204_L3.6mm_D1.6mm_P7.62mm_Horizontal
R2: R; R_Axial_DIN0204_L3.6mm_D1.6mm_P7.62mm_Horizontal
R3: 220; R_Axial_DIN0204_L3.6mm_D1.6mm_P7.62mm_Horizontal
RV1: 10k; Potentiometer_Bourns_3296X_Horizontal
SW1, SW3: Reset Switch; SW_PUSH_6mm
SW2: SW_SPST; SW_DIP_SPSTx01_Slide_9.78x4.72mm_W7.62mm_P2.54mm
U1: W65C02SxP; DIP-40_W15.24mm
U2: 28C256; DIP-28_W15.24mm
U3: CY62256-70PC; DIP-28_W15.24mm
U4: W65C51NxP; DIP-28_W15.24mm
U5: MAX232; DIP-16_W10.16mm
U6: 74HC00; DIP-14_W7.62mm
U7: W65C22NxP; DIP-40_W15.24mm
U8: LM317_TO-220; TO-220-3_Vertical
U9: DS1813-10; 21-0248A_MXM
X1: ACO-1MHz; Oscillator_DIP-14
Y1: 1.8432Mhz; Crystal_HC18-U_Vertical

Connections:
3.3v: C14.1, J9.2, JP1.3 (B), U8.2 (VO)
!A15: U2.20 (~CS), U6.3, U6.10, U6.13
A0: J9.5, U1.9 (A0), U2.10 (A0), U3.10 (A0), U4.13 (RS0), U7.38 (RS0)
A1: J9.7, U1.10 (A1), U2.9 (A1), U3.9 (A1), U4.14 (RS1), U7.37 (RS1)
A2: J9.9, U1.11 (A2), U2.8 (A2), U3.8 (A2), U7.36 (RS2)
A3: J9.11, U1.12 (A3), U2.7 (A3), U3.7 (A3), U7.35 (RS3)
A4: J9.13, U1.13 (A4), U2.6 (A4), U3.6 (A4)
A5: J9.15, U1.14 (A5), U2.5 (A5), U3.5 (A5)
A6: J9.17, U1.15 (A6), U2.4 (A6), U3.4 (A6)
A7: J9.19, U1.16 (A7), U2.3 (A7), U3.3 (A7)
A8: J9.21, U1.17 (A8), U2.25 (A8), U3.25 (A8)
A9: J9.23, U1.18 (A9), U2.24 (A9), U3.24 (A9)
A10: J9.25, U1.19 (A10), U2.21 (A10), U3.21 (A10)
A11: J9.27, U1.20 (A11), U2.23 (A11), U3.23 (A11)
A12: J9.29, U1.22 (A12), U2.2 (A12), U3.2 (A12), U4.2 (CS1)
A13: J9.31, U1.23 (A13), U2.26 (A13), U3.26 (A13), U7.24 (CS1)
A14: J9.33, U1.24 (A14), U2.1 (A14), U3.1 (A14), U3.22 (~OE), U6.9
A15: J9.35, U1.25 (A15), U6.1, U6.2
D0: J9.6, U1.33 (D0), U2.11 (D0), U3.11 (Q0), U4.18 (D0), U7.33 (D0)
D1: J9.8, U1.32 (D1), U2.12 (D1), U3.12 (Q1), U4.19 (D1), U7.32 (D1)
D2: J9.10, U1.31 (D2), U2.13 (D2), U3.13 (Q2), U4.20 (D2), U7.31 (D2)
D3: J9.12, U1.30 (D3), U2.15 (D3), U3.15 (Q3), U4.21 (D3), U7.30 (D3)
D4: J9.14, U1.29 (D4), U2.16 (D4), U3.16 (Q4), U4.22 (D4), U7.29 (D4)
D5: J9.16, U1.28 (D5), U2.17 (D5), U3.17 (Q5), U4.23 (D5), U7.28 (D5)
D6: J9.18, U1.27 (D6), U2.18 (D6), U3.18 (Q6), U4.24 (D6), U7.27 (D6)
D7: J9.20, U1.26 (D7), U2.19 (D7), U3.19 (Q7), U4.25 (D7), U7.26 (D7)
GND: C1.2, C2.2, C3.2, C4.2, C7.2, C8.2, C9.2, C10.2, C11.2, C12.2, C13.2, C14.2, D3.1 (K), J1.5, J2.4 (GND), J2.5 (Shield), J5.1, J5.16, J6.1, J7.1, J9.3, J9.4, J9.37, RV1.1, SW1.1, SW3.1, U1.21 (VSS), U2.14 (GND), U2.22 (~OE), U3.14 (GND), U4.1 (VSS), U5.15 (GND), U6.7 (GND), U7.1 (VSS), U8.1 (ADJ), U9.3 (GND), X1.7 (GND)
IRQ: D1.2 (A), D2.2 (A), J9.30, U1.4 (~IRQ)
unnamed: D1.1 (K), U7.21 (~IRQ)
unnamed: D2.1 (K), U4.26 (~IRQ)
unnamed: D3.2 (A), R3.2
unnamed: J2.1 (VBUS), SW2.1 (A)
unnamed: J5.3, RV1.2
unnamed: J6.2, J7.3, JP1.2 (C)
unnamed: J1.8, J7.2, U4.9 (~CTS)
unnamed: J1.2, J7.4, U5.14 (T1OUT)
unnamed: J1.3, J7.5, U5.13 (R1IN)
unnamed: J1.4, J7.6, U4.11 (~DTR)
unnamed: U3.20 (~CS), U6.11
unnamed: R2.1, U4.6 (XTAL1), Y1.2
unnamed: C2.1, R2.2, U4.7 (XTAL2), Y1.1
unnamed: U4.3 (~CS2), U6.8, U7.23 (~CS2)
unnamed: J1.6, U4.17 (~DSR)
unnamed: J1.7, U4.8 (~RTS)
unnamed: C5.1, U5.1 (C1+)
unnamed: C5.2, U5.3 (C1-)
unnamed: C6.1, U5.4 (C2+)
unnamed: C6.2, U5.5 (C2-)
unnamed: C4.1, U5.2 (VS+)
unnamed: C3.1, U5.6 (VS-)
PA0: J4.8, J6.3, U7.2 (PA0)
PA1: J4.7, J6.4, U7.3 (PA1)
PA2: J4.6, J6.5, U7.4 (PA2)
PA3: J4.5, J6.6, U7.5 (PA3)
PA4: J4.4, J9.22, U7.6 (PA4)
PA5: J4.3, J5.4, J9.24, U7.7 (PA5)
PA6: J4.2, J5.5, J9.26, U7.8 (PA6)
PA7: J4.1, J5.6, U7.9 (PA7)
PB0: J3.8, J5.7, U7.10 (PB0)
PB1: J3.7, J5.8, U7.11 (PB1)
PB2: J3.6, J5.9, U7.12 (PB2)
PB3: J3.5, J5.10, U7.13 (PB3)
PB4: J3.4, J5.11, U7.14 (PB4)
PB5: J3.3, J5.12, U7.15 (PB5)
PB6: J3.2, J5.13, U7.16 (PB6)
PB7: J3.1, J5.14, U7.17 (PB7)
RW: J9.32, U1.34 (R/~W), U3.27 (~WE), U4.28 (R/~W), U7.22 (R/~W)
RXD: U4.12 (RxD), U5.12 (R1OUT)
Reset: C1.1, J9.28, R1.2, SW1.2, SW3.2, U1.40 (~RES), U4.4 (~RES), U7.34 (~RES), U9.1 (~R~~S~~T~)
TXD: U4.10 (TxD), U5.11 (T1IN)
VCC: C7.1, C8.1, C9.1, C10.1, C11.1, C12.1, C13.1, J5.2, J5.15, J9.1, JP1.1 (A), R1.1, R3.1, SW2.2 (B), U1.2 (RDY), U1.6 (~NMI), U1.8 (VDD), U1.36 (BE), U2.27 (~WE), U2.28 (VCC), U3.28 (VCC), U4.15 (VCC), U5.16 (VCC), U6.14 (VCC), U7.20 (VCC), U8.3 (VI), U9.2 (VCC), X1.14 (Vcc)
clock: J9.36, U1.37 (ϕ0), U4.27 (ϕ2), U6.12, U7.25 (ϕ2), X1.8 (OUT)

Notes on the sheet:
6502 SBC Computer with SD Card / TFDI Serial / DB9 and Expansion Port (Tom Smith)

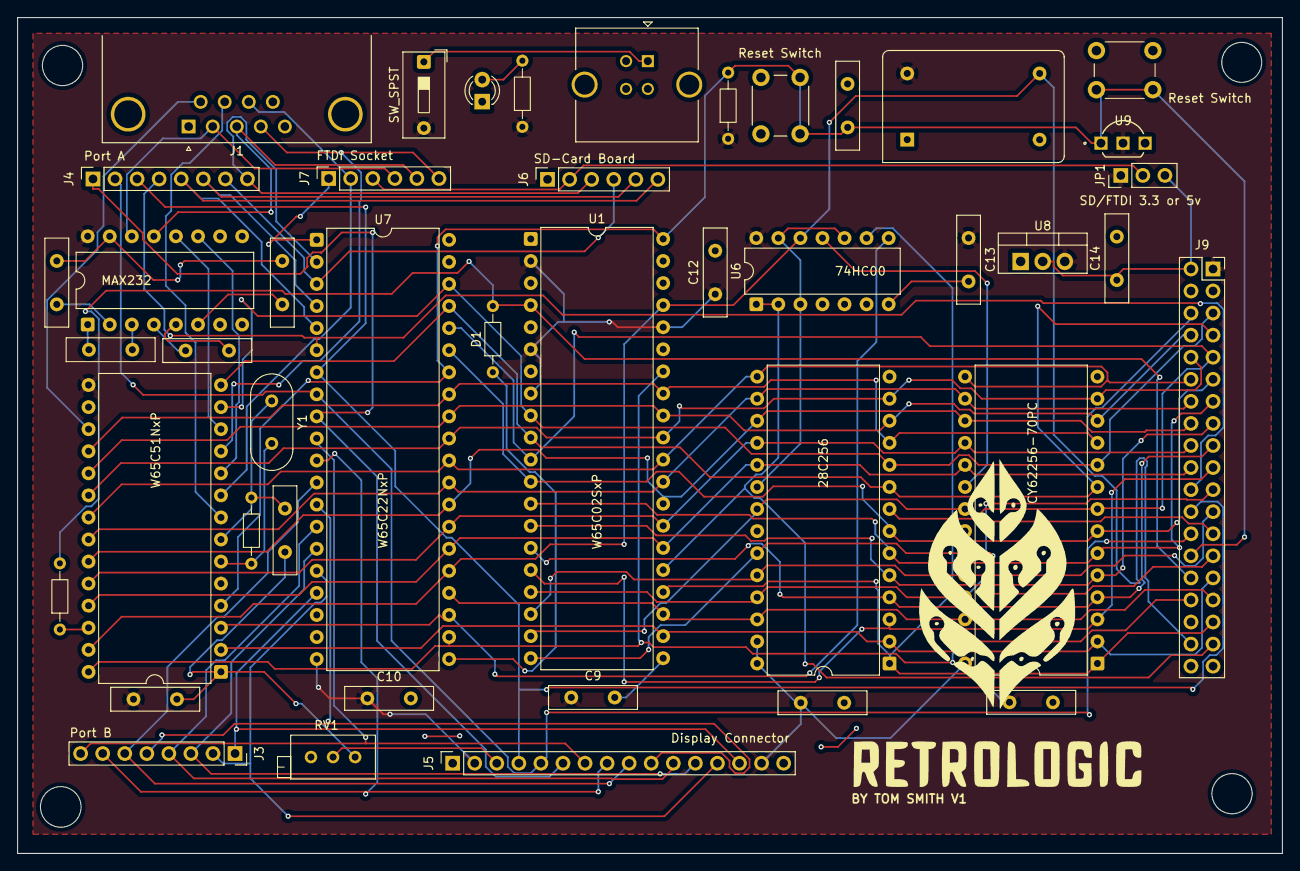
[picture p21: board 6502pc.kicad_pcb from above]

Board: 2 copper layers, 145.6 x 96.2 mm, 44 parts (0 on the bottom side), 72 nets.

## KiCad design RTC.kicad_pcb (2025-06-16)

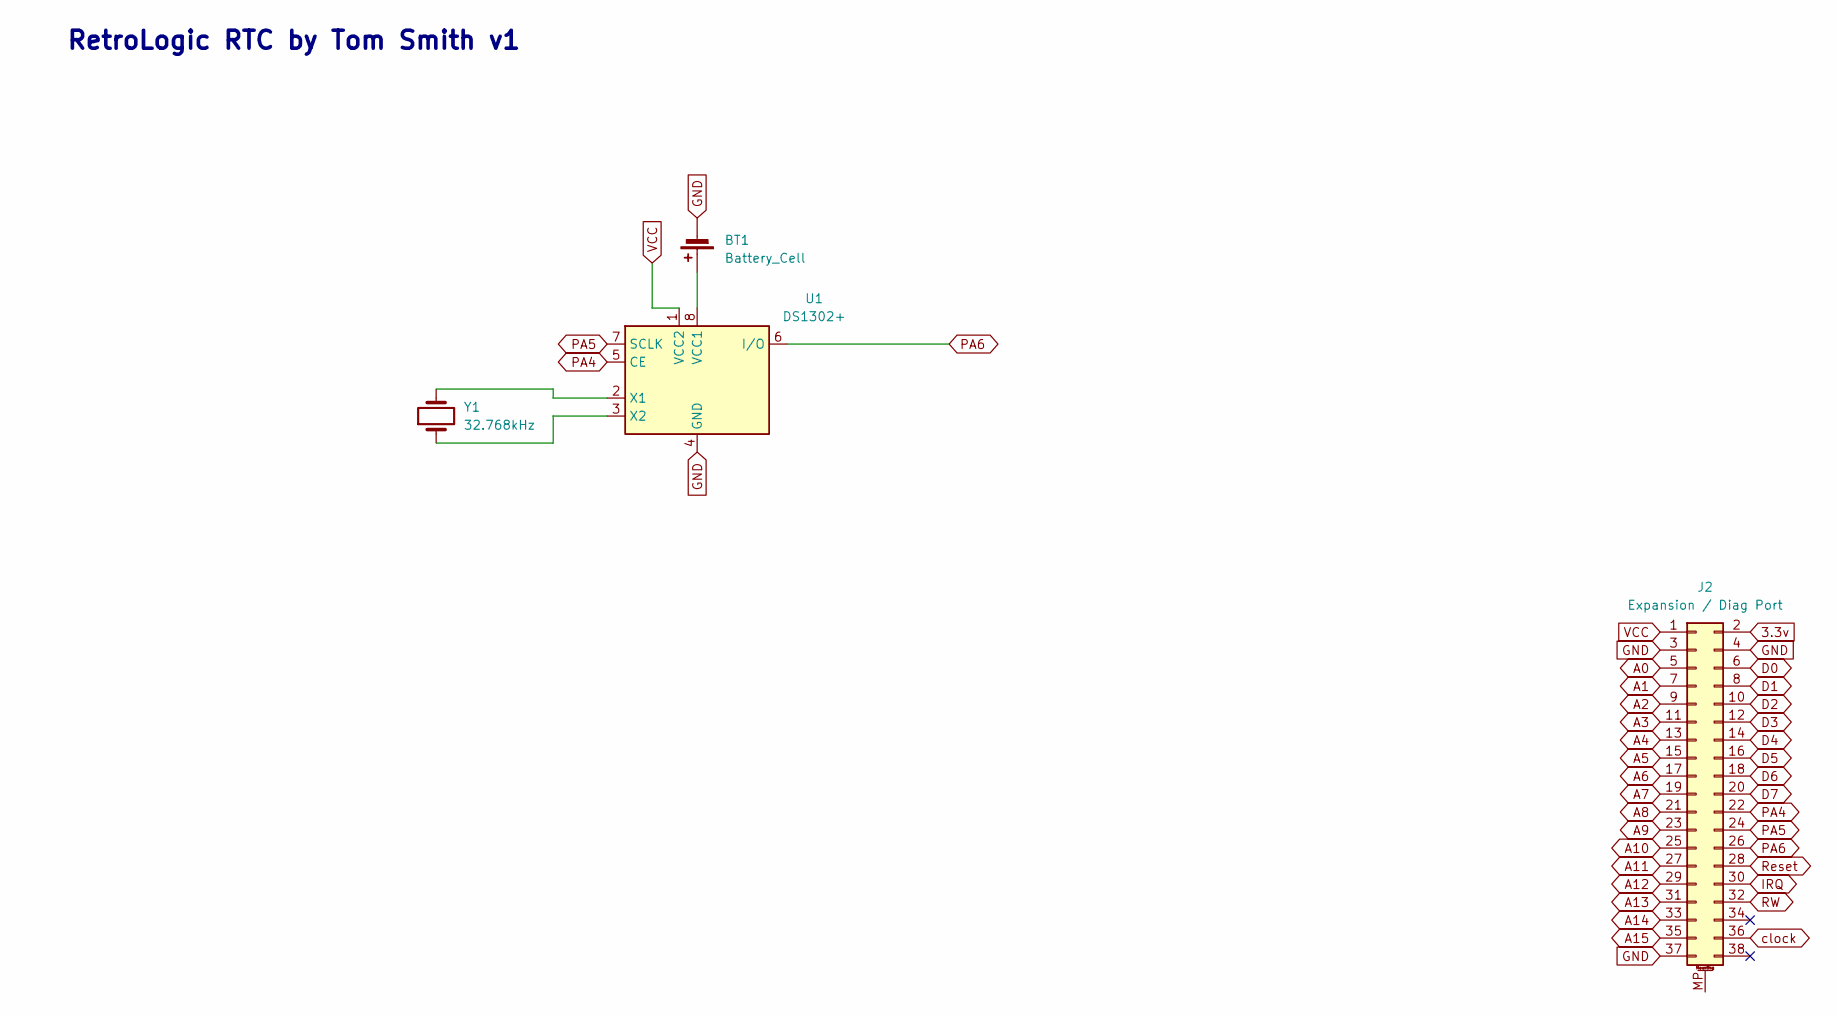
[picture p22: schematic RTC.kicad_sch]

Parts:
BT1: Battery_Cell; Battery_Panasonic_CR2032-HFN_Horizontal_CircularHoles
J2: Expansion / Diag Port; PinHeader_2x19_P2.54mm_Vertical
U1: DS1302+; DIP-8_W7.62mm
Y1: 32.768kHz; Crystal_DS15_D1.5mm_L5.0mm_Horizontal

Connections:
3.3v: J2.2
A0: J2.5
A1: J2.7
A2: J2.9
A3: J2.11
A4: J2.13
A5: J2.15
A6: J2.17
A7: J2.19
A8: J2.21
A9: J2.23
A10: J2.25
A11: J2.27
A12: J2.29
A13: J2.31
A14: J2.33
A15: J2.35
D0: J2.6
D1: J2.8
D2: J2.10
D3: J2.12
D4: J2.14
D5: J2.16
D6: J2.18
D7: J2.20
GND: BT1.2 (-), J2.3, J2.4, J2.37, U1.4 (GND)
IRQ: J2.30
unnamed: BT1.1 (+), U1.8 (VCC1)
unnamed: U1.2 (X1), Y1.2
unnamed: U1.3 (X2), Y1.1
PA4: J2.22, U1.5 (CE)
PA5: J2.24, U1.7 (SCLK)
PA6: J2.26, U1.6 (I/O)
RW: J2.32
Reset: J2.28
VCC: J2.1, U1.1 (VCC2)
clock: J2.36

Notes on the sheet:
RetroLogic RTC by Tom Smith v1

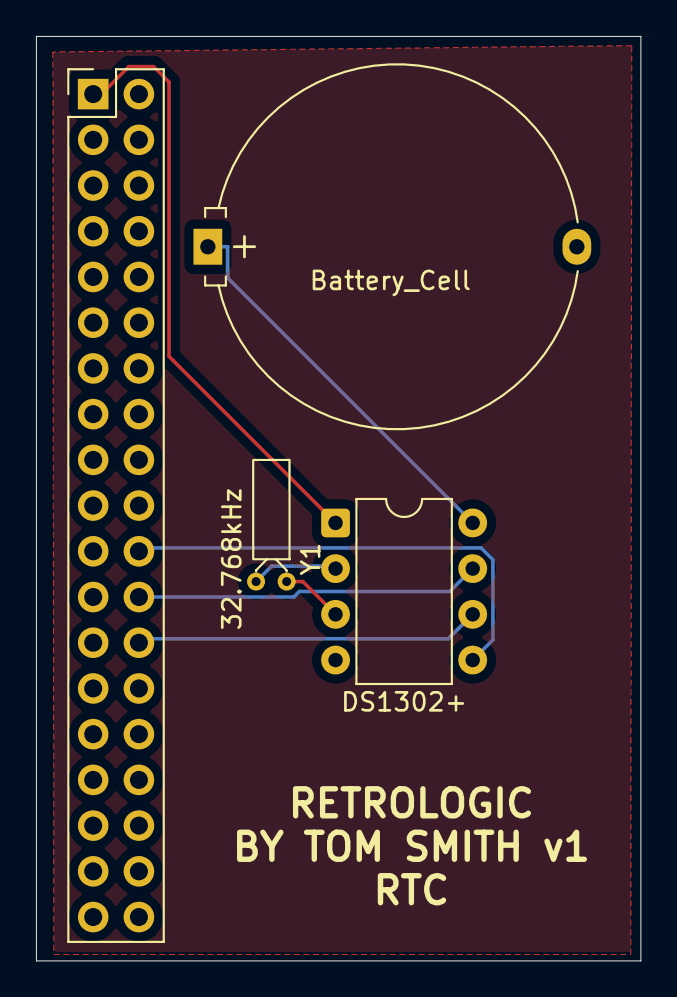
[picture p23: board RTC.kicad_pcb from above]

Board: 2 copper layers, 33.6 x 51.4 mm, 4 parts (0 on the bottom side), 8 nets.

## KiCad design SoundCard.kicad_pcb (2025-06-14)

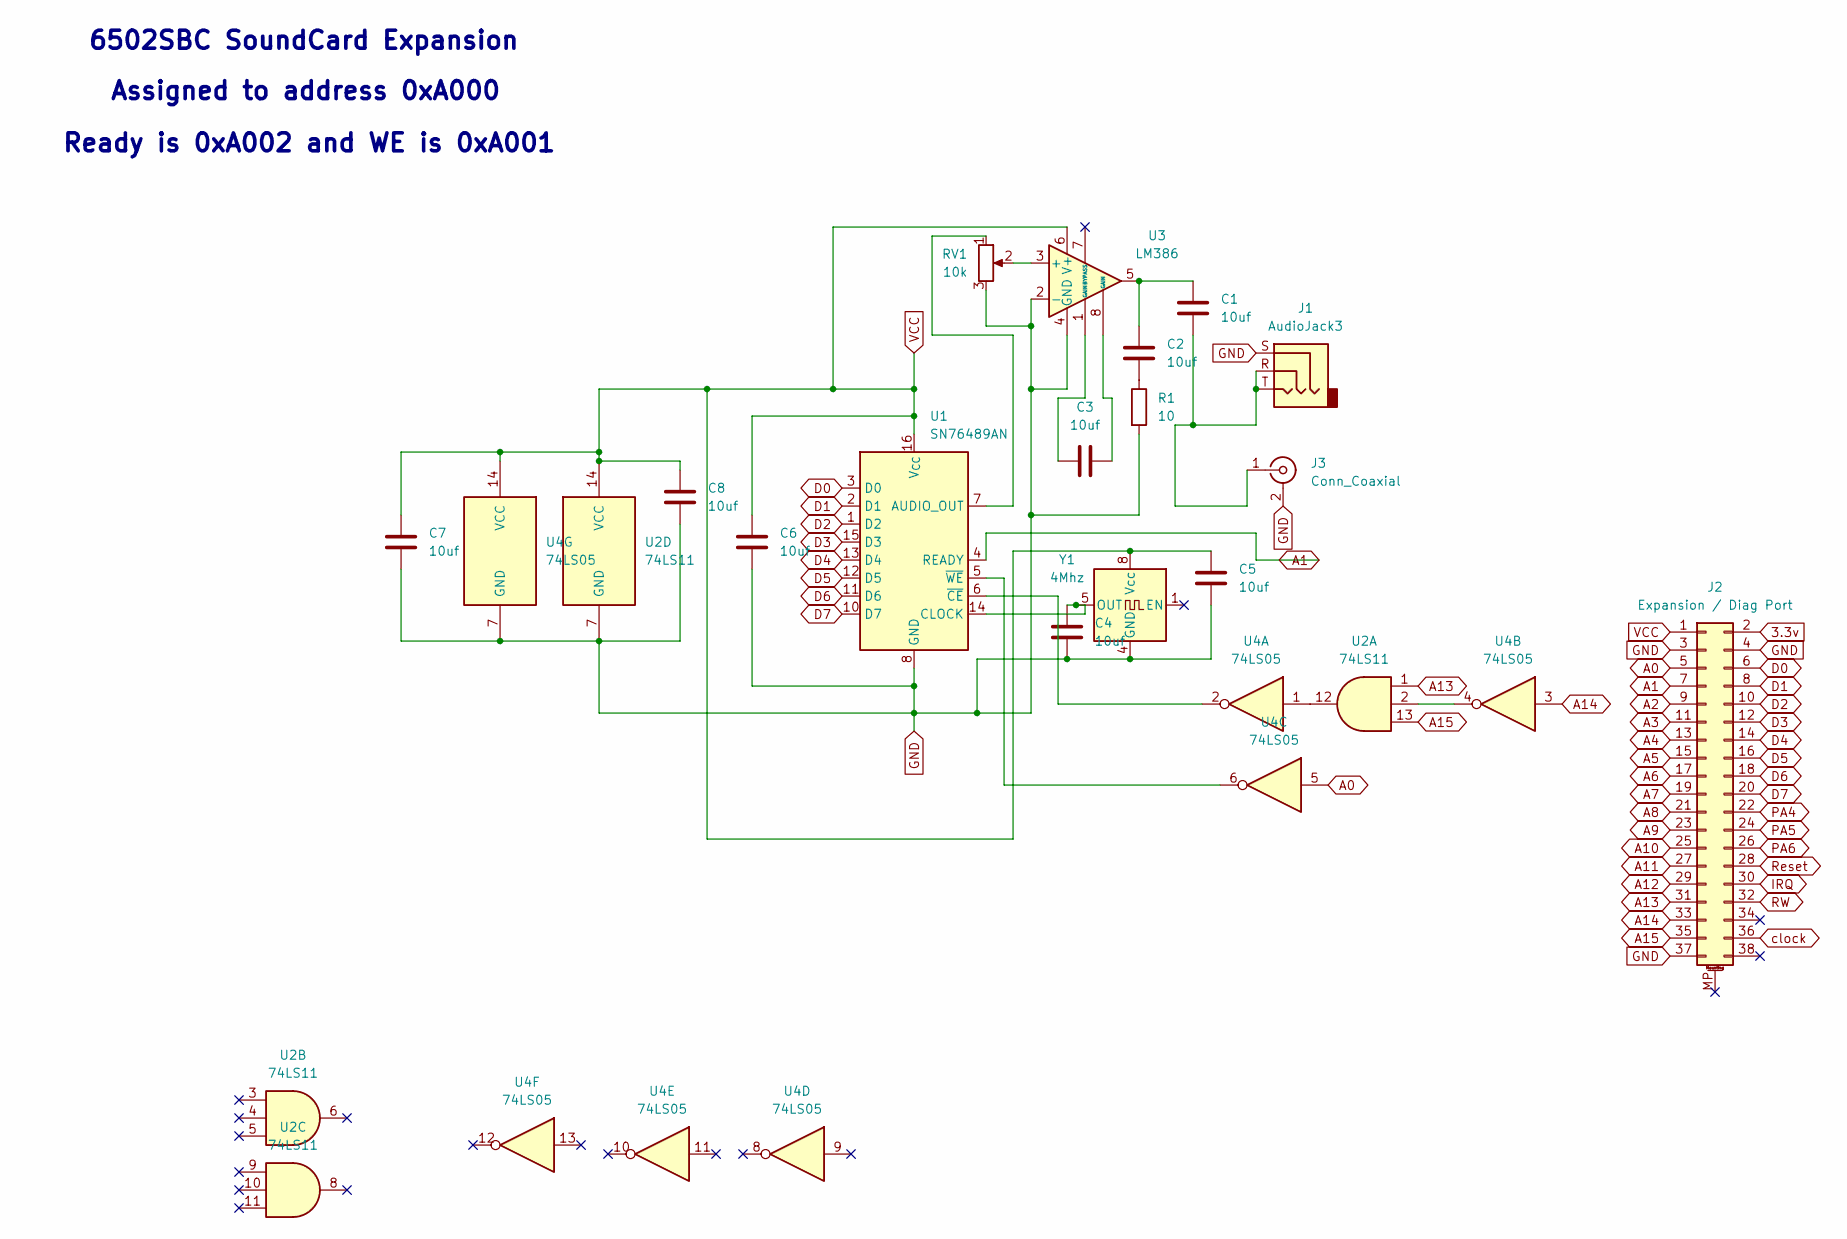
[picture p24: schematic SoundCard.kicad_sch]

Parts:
C1, C2: 10uf; R_Axial_DIN0204_L3.6mm_D1.6mm_P5.08mm_Horizontal
C3, C4, C5, C6, C7, C8: 10uf; C_Disc_D4.3mm_W1.9mm_P5.00mm
J1: AudioJack3; Jack_3.5mm_CUI_SJ1-3513N_Horizontal
J2: Expansion / Diag Port; PinHeader_2x19_P2.54mm_Vertical
J3: Conn_Coaxial; BNC_Amphenol_B6252HB-NPP3G-50_Horizontal
R1: 10; R_Axial_DIN0204_L3.6mm_D1.6mm_P5.08mm_Horizontal
RV1: 10k; Potentiometer_Bourns_3296W_Vertical
U1: SN76489AN; DIP-16_W7.62mm
U2: 74LS11; DIP-14_W7.62mm
U3: LM386; DIP-8_W7.62mm
U4: 74LS05; DIP-14_W7.62mm
Y1: 4Mhz; Oscillator_DIP-8

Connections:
3.3v: J2.2
A0: J2.5, U4.5
A1: J2.7, U1.4 (READY)
A2: J2.9
A3: J2.11
A4: J2.13
A5: J2.15
A6: J2.17
A7: J2.19
A8: J2.21
A9: J2.23
A10: J2.25
A11: J2.27
A12: J2.29
A13: J2.31, U2.1
A14: J2.33, U4.3
A15: J2.35, U2.13
D0: J2.6, U1.3 (D0)
D1: J2.8, U1.2 (D1)
D2: J2.10, U1.1 (D2)
D3: J2.12, U1.15 (D3)
D4: J2.14, U1.13 (D4)
D5: J2.16, U1.12 (D5)
D6: J2.18, U1.11 (D6)
D7: J2.20, U1.10 (D7)
GND: C4.1, C5.1, C6.1, C7.1, C8.1, J1.S, J2.3, J2.4, J2.37, J3.2 (Ext), R1.2, RV1.3, U1.8 (GND), U2.7 (GND), U3.2 (-), U3.4 (GND), U4.7 (GND), Y1.4 (GND)
IRQ: J2.30
unnamed: C1.1, C2.1, U3.5
unnamed: C2.2, R1.1
unnamed: C3.1, U3.1 (GAIN)
unnamed: C3.2, U3.8 (GAIN)
unnamed: C1.2, J1.R, J1.T, J3.1 (In)
unnamed: RV1.1, U1.7 (AUDIO_OUT)
unnamed: C4.2, U1.14 (CLOCK), Y1.5 (OUT)
unnamed: U1.6 (~CE), U4.2
unnamed: U1.5 (~WE), U4.6
unnamed: U2.2, U4.4
unnamed: U2.12, U4.1
unnamed: RV1.2, U3.3 (+)
PA4: J2.22
PA5: J2.24
PA6: J2.26
RW: J2.32
Reset: J2.28
VCC: C5.2, C6.2, C7.2, C8.2, J2.1, U1.16 (V_{CC}), U2.14 (VCC), U3.6 (V+), U4.14 (VCC), Y1.8 (Vcc)
clock: J2.36

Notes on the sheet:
Ready is 0xA002 and WE is 0xA001
Assigned to address 0xA000
6502SBC SoundCard Expansion

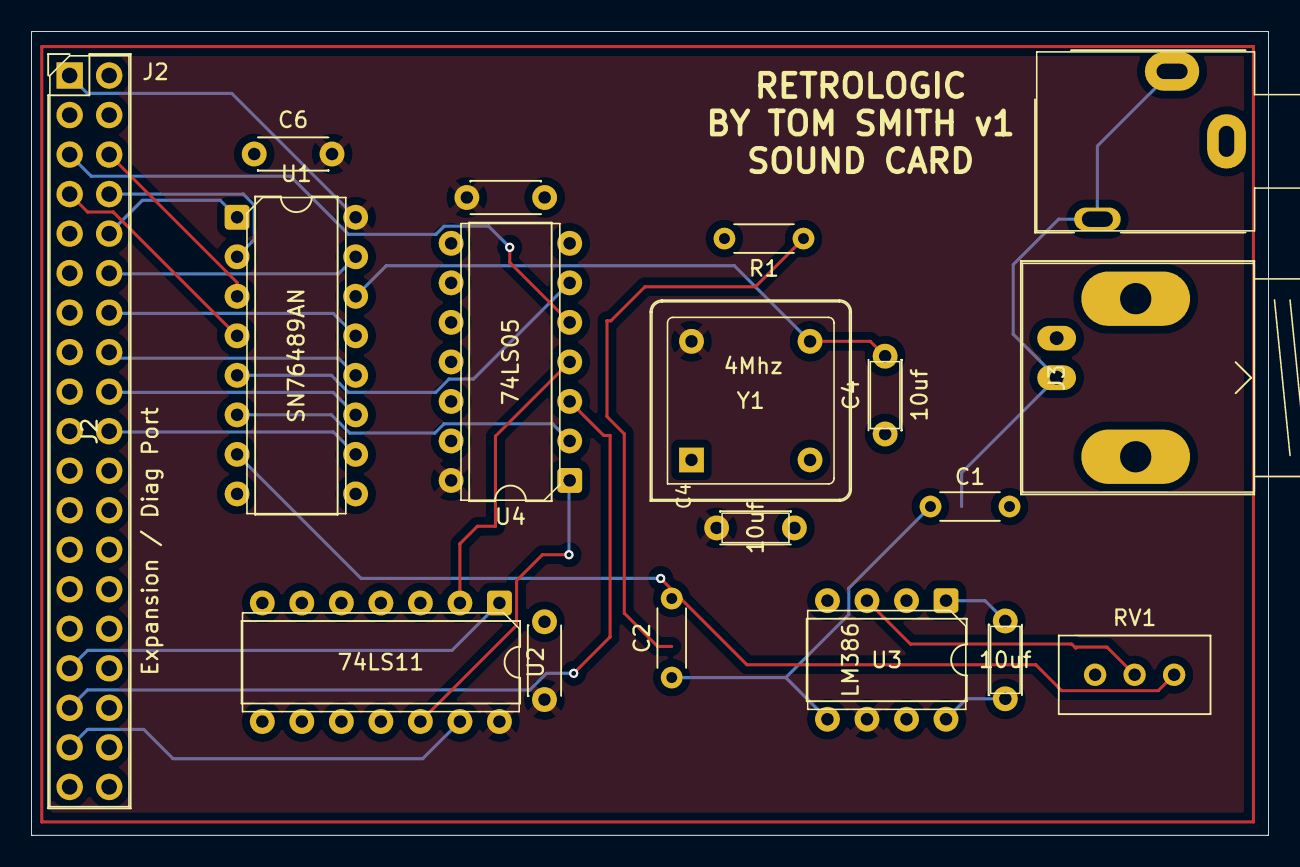
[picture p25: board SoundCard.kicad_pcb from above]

Board: 2 copper layers, 79.5 x 51.7 mm, 18 parts (0 on the bottom side), 27 nets.

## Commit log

2025-06-01 First Version
    [6502pc.kicad_pcb, 6502pc.kicad_sch]
2025-06-01 Added Expansion
    [6502pc.kicad_sch]
2025-06-06 Add Sound Card
    [SoundCard.kicad_sch]
2025-06-08 Finished Sound Card
    [SoundCard-B_Cu.gbr, SoundCard-B_Mask.gbr, SoundCard-B_Paste.gbr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]
2025-06-11 Routing and added auto reset
    [6502pc-B_Cu.gbr, 6502pc-B_Mask.gbr, 6502pc-B_Paste.gbr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]
2025-06-11 More corrections
    [SoundCard-B_Cu.gbr, SoundCard-B_Mask.gbr, SoundCard-B_Paste.gbr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]
2025-06-11 bom and sound app
    [6502ExpBoard.kicad_pcb, 6502pc.kicad_pcb, 6502pc.kicad_sch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]
2025-06-13 Minor Changes
    [SoundCard-B_Cu.gbr, SoundCard-B_Mask.gbr, SoundCard-B_Paste.gbr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]
2025-06-16 Added RTC v1
    [RTC.kicad_pcb, RTC.kicad_sch]
2025-06-27 Terminal Card Addition
    [6502pc.kicad_sch, PIC32MX250F128B-V_SP.step, TerminalCard.kicad_pcb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]
2025-07-07 Diag Board led fixes
    [6502ExpBoard.kicad_pcb, 6502ExpBoard.kicad_sch]
